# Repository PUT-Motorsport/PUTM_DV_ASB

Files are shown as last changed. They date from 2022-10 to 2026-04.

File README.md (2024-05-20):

# PUTM_DV_ASB_2023
Autonomus Brake System PCB and Software for PM07

Functionality:
Solenoid valves control,
Pressure sensors data acquisition,
Functional safety, and hard-wired logic implementation,
Autonomous System SDC driver,
RES communication bridge.

Important links:

FSG Rules:
fsg.one/rules

Previous board (unusable)

ASF Examples:
https://www.formulastudent.de/academy/hands-on/asf/

FSG Academy:
https://www.formulastudent.de/fileadmin/user_upload/all/2022/important_docs/FSG21_AS_Beginners_Guide_v1.0.pdf

Jakub's Mechanical construction:
https://files.podio.com/1561594165

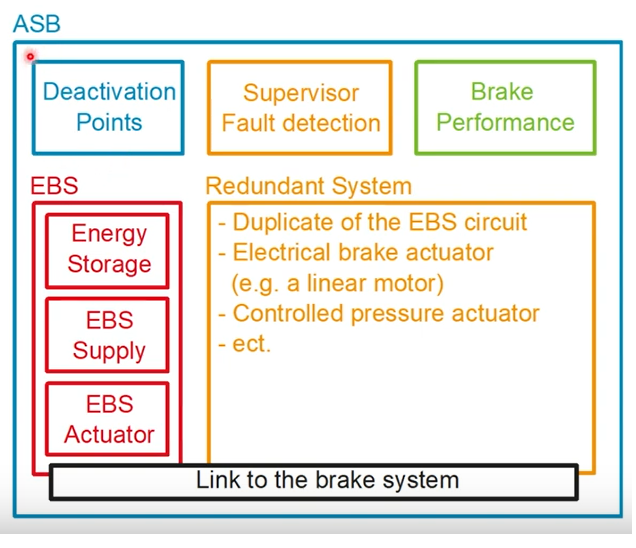
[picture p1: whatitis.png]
ASB


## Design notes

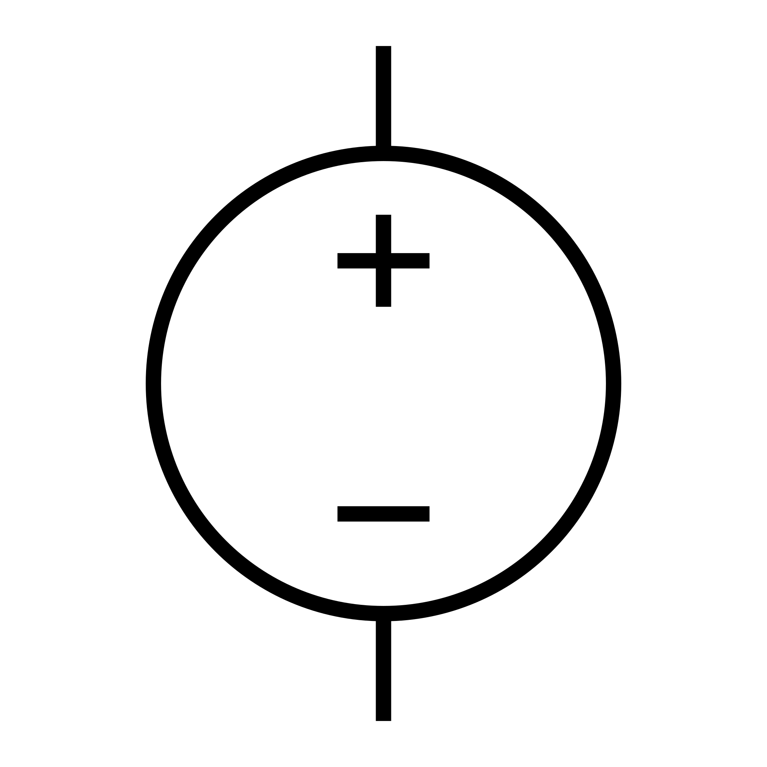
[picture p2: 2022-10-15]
hardware/Voltage_Source.svg.png

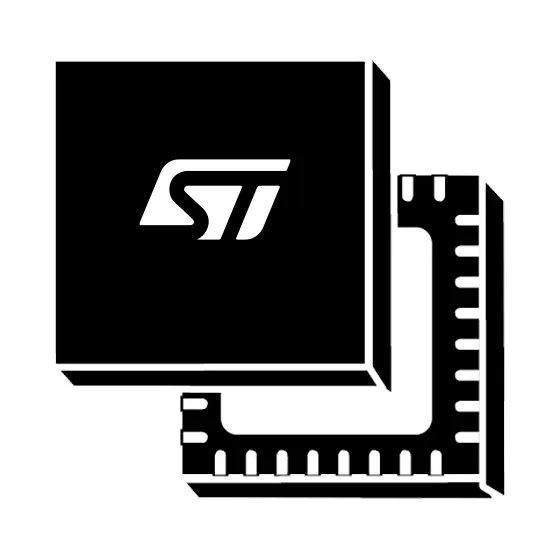
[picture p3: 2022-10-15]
hardware/ufqfpn-48-7x7x0_6.webp

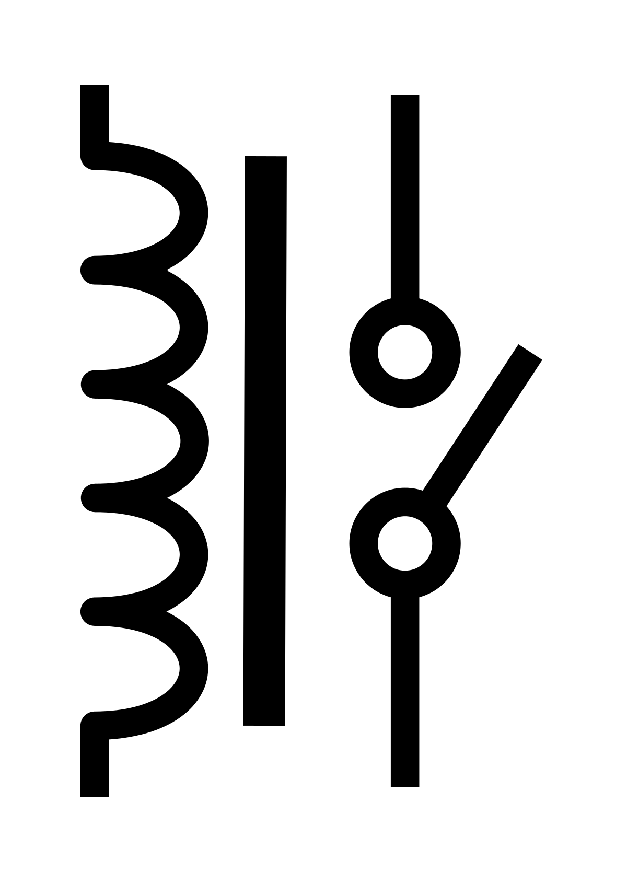
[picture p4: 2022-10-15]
hardware/1200px-SPST-NO_relay_symbol.svg.png

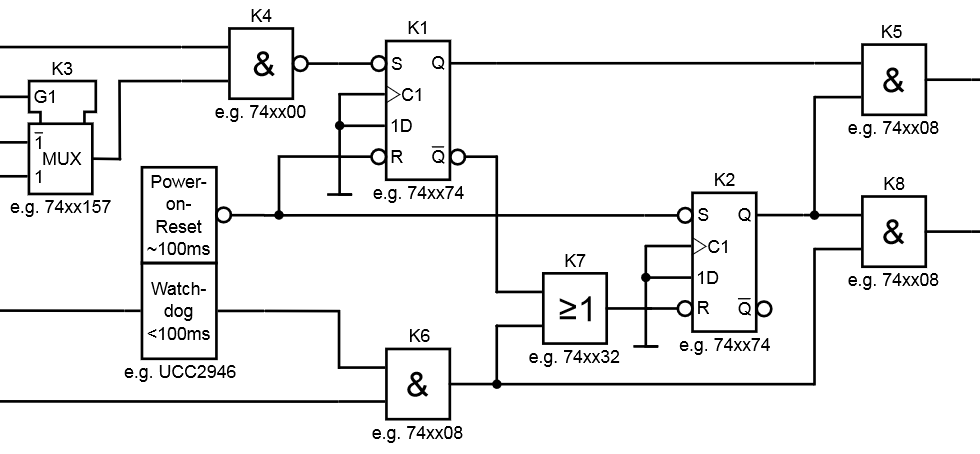
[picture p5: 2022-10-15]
hardware/reference.bmp

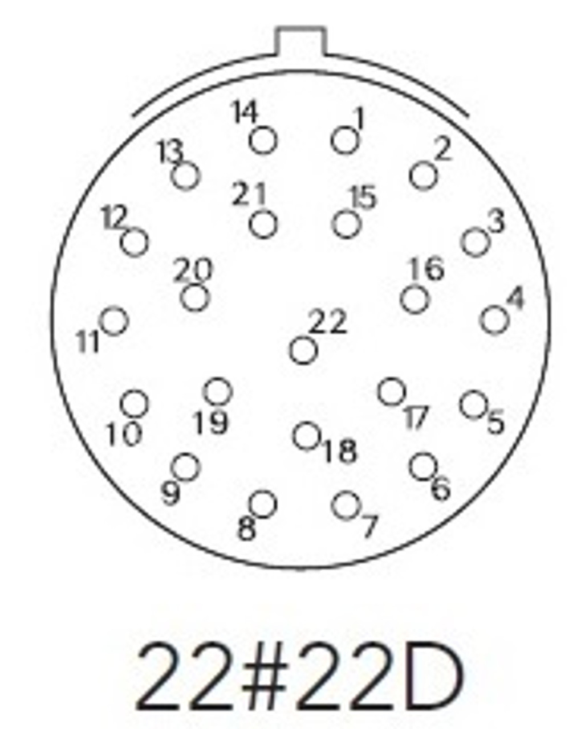
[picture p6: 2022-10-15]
hardware/1235k__19089.jpg

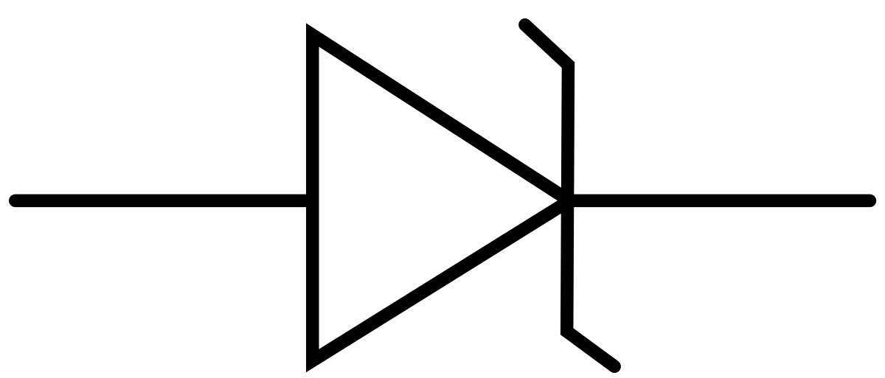
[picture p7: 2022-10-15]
hardware/1200px-Zener_diode_symbol-2.svg.png

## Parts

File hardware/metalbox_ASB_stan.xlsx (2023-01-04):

Designator | Footprint | Quantity | Value | LCSC Part #
C1 | C_0603_1608Metric_Pad1.08x0.95mm_HandSolder | 1 | 10n 1%
C10, C12, C14, C18, C2, C23, C27, C28, C32, C33, C4, C7, C8, C9 | C_0603_1608Metric_Pad1.08x0.95mm_HandSolder | 14 | 100nF
C11, C13 | C_0603_1608Metric_Pad1.08x0.95mm_HandSolder | 2 | 22pF
C15 | C_0805_2012Metric_Pad1.18x1.45mm_HandSolder | 1 | 100nF
C16, C17, C19 | C_0603_1608Metric_Pad1.08x0.95mm_HandSolder | 3 | 100n
C20 | C_0603_1608Metric_Pad1.08x0.95mm_HandSolder | 1 | 10u
C29, C30, C31, C5 | C_0603_1608Metric_Pad1.08x0.95mm_HandSolder | 4 | 10nF
C3 | C_0603_1608Metric_Pad1.08x0.95mm_HandSolder | 1 | 4,7nF 1%
C34, C35, C36 | C_0603_1608Metric_Pad1.08x0.95mm_HandSolder | 3 | 5.6n
C37, C38, C39 | C_0603_1608Metric | 3 | 100nF
C6 | C_0603_1608Metric_Pad1.08x0.95mm_HandSolder | 1 | 1uF
Cb_infltr1 | CP_Elec_4x5.4 | 1 | 4,7uF 3Ohm
Cboot1 | C_0402_1005Metric_Pad0.74x0.62mm_HandSolder | 1 | 100nF 1mOhm
Cf_infltr1, Cf_infltr2, Cf_infltr3 | C_1210_3225Metric_Pad1.33x2.70mm_HandSolder | 3 | 10uF 1mOhm
Cin1 | C_0805_2012Metric_Pad1.18x1.45mm_HandSolder | 1 | 4,7uF 1mOhm
Cinx1 | C_0805_2012Metric_Pad1.18x1.45mm_HandSolder | 1 | 100nF 64mOhm
Cout1 | C_1206_3216Metric_Pad1.33x1.80mm_HandSolder | 1 | 47uF 3,037mOhm
D1, D10, D13, D14, D15 | D_SOD-323_HandSoldering | 5 | BZX38450-C3V3-QX
D11 | LED_0603_1608Metric_Pad1.05x0.95mm_HandSolder | 1 | LED 5V
D12, D3, D4, D5 | D_SMA_Handsoldering | 4 | SK36A
D16, D17, D18, D6 | LED_0603_1608Metric_Pad1.05x0.95mm_HandSolder | 4 | LED
D2 | SOT-23 | 1 | PESD2CAN.215
D7 | D_SMB | 1 | SD24-SOD323
D8 | LED_0603_1608Metric_Pad1.05x0.95mm_HandSolder | 1 | LED 3.3
F1 | Fuse_1206_3216Metric | 1 | 1A
IC1 | SOIC127P600X175-8N | 1 | UCC2946DG4
IC2, IC3 | SOP65P400X130-8N | 2 | SN74LVC1G74DCTR
J1 | M80-5L104YYMC | 1 | SAFETY_SUPPLY
J2 | PinHeader_1x05_P2.54mm_Vertical | 1 | SWDIO_CONN
J3 | M80-5L104YYMC | 1 | SENSORS
J4 | M80-5L104YYMC | 1 | VALVES
J5 | M80-5L112YYMC | 1 | MAIN
JP1 | PinHeader_1x02_P2.54mm_Vertical | 1 | Jumper_NC_Small
K1, K2 | Relay_DPDT_Finder_30.22 | 2 | FINDER-30.22
L1 | L_0805_2012Metric | 1 | 10u
LF_infltr1 | L_0805_2012Metric_Pad1.05x1.20mm_HandSolder | 1 | 1.5uH 260mOhm
L_SW1 | L_Bourns_EBS | 1 | 22uH 36mOhm
PUTM_LOGO | PUTM_LOGO_15mm | 1 | LOGO
Q1, Q2, Q3, Q4 | SOT-23 | 4 | BSS123
R1, R14, R16, R18, R19, R40, R43, R46 | R_0603_1608Metric_Pad0.98x0.95mm_HandSolder | 8 | 1k
R10, R28, R30, R32 | R_0603_1608Metric_Pad0.98x0.95mm_HandSolder | 4 | 22k
R11, R29, R31, R33 | R_0603_1608Metric_Pad0.98x0.95mm_HandSolder | 4 | 3k
R12, R15, R17, R27, R3, R6, R7 | R_0603_1608Metric_Pad0.98x0.95mm_HandSolder | 7 | 10k
R13 | R_0603_1608Metric_Pad0.98x0.95mm_HandSolder | 1 | 120R
R2, R20, R25, R35, R36, R37, R4, R47, R5 | R_0603_1608Metric_Pad0.98x0.95mm_HandSolder | 9 | 2.2k
R38, R41, R44 | R_0603_1608Metric_Pad0.98x0.95mm_HandSolder | 3 | 3.3k 1%
R39, R42, R45 | R_0603_1608Metric_Pad0.98x0.95mm_HandSolder | 3 | 6.8k 1%
R8 | R_0603_1608Metric_Pad0.98x0.95mm_HandSolder | 1 | 4k7 1%
R9 | R_0603_1608Metric_Pad0.98x0.95mm_HandSolder | 1 | 3k3 1%
Rd_infltr1 | R_0603_1608Metric_Pad0.98x0.95mm_HandSolder | 1 | 0.1R
Rfbb1 | R_0402_1005Metric_Pad0.72x0.64mm_HandSolder | 1 | 10kOhm
Rfbt1 | R_0402_1005Metric_Pad0.72x0.64mm_HandSolder | 1 | 23,2kOhm
Rpgood1 | R_0603_1608Metric_Pad0.98x0.95mm_HandSolder | 1 | 100kOhm
Rt1 | R_0603_1608Metric_Pad0.98x0.95mm_HandSolder | 1 | 64,9kOhm
TP1 | PinHeader_1x07_P2.54mm_Vertical | 1 | PinHeader_1x07_P2.54mm_Vertical
TP2 | PinHeader_1x06_P2.54mm_Vertical | 1 | PinHeader_1x06_P2.54mm_Vertical
U1 | VSSOP-8_2.3x2mm_P0.5mm | 1 | 74157
U10, U8, U9 | SOT-23-5_HandSoldering | 3 | TSX7191
U11 | TI_SO-PowerPAD-8_ThermalVias | 1 | LMR38010SDDAR
U2 | TSSOP-14_4.4x5mm_P0.65mm | 1 | 4011
U3 | TSSOP-14_4.4x5mm_P0.65mm | 1 | 4081
U4 | TSSOP-14_4.4x5mm_P0.65mm | 1 | 4071
U5 | LQFP-64_10x10mm_P0.5mm | 1 | STM32L4P5RET6
U6 | SOIC-8_3.9x4.9mm_P1.27mm | 1 | MCP2562-H-SN
U7 | TO-252-3_TabPin2 | 1 | LM1117-3.3
Y1 | Crystal_SMD_3225-4Pin_3.2x2.5mm | 1 | Crystal_GND24

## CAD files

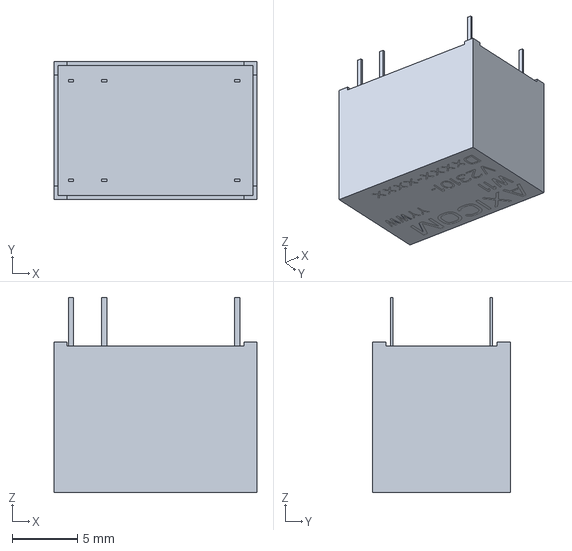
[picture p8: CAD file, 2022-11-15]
hardware/2-1393779-0.stp
15.5 x 10.5 x 14.9 mm

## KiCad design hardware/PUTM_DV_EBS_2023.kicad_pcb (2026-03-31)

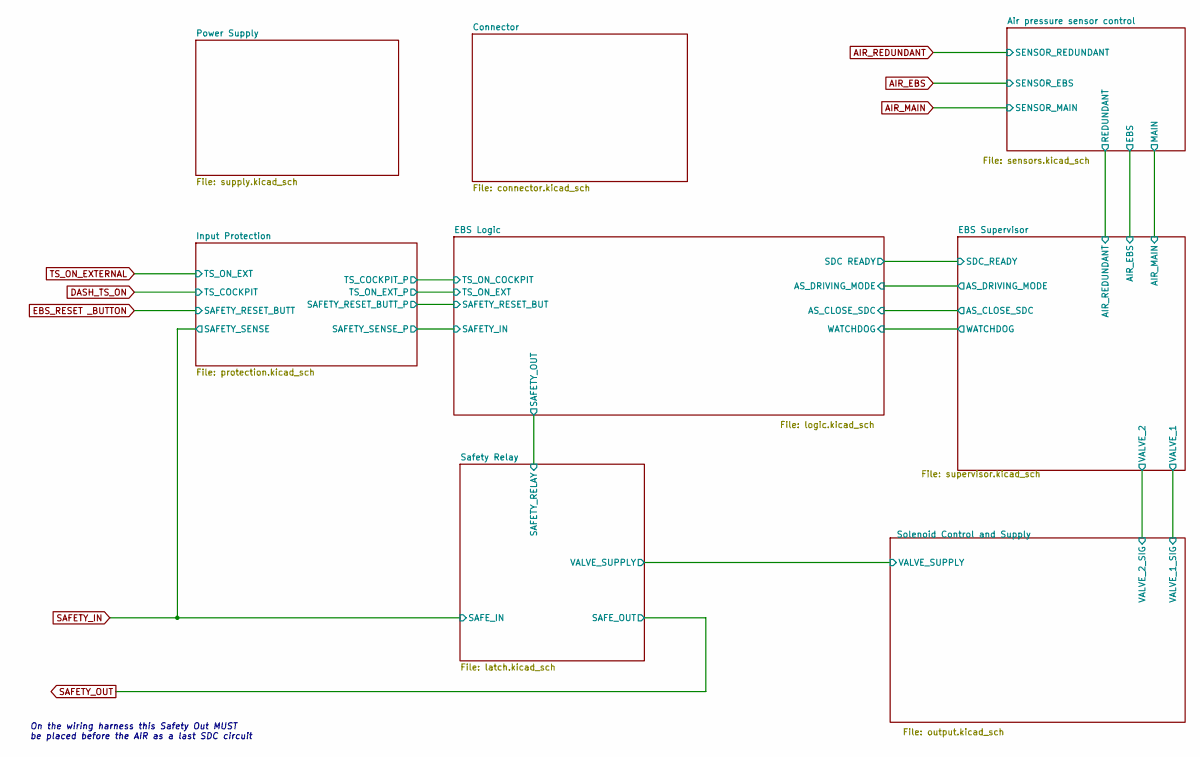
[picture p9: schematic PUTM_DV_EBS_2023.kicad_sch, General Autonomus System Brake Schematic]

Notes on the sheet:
On the wiring harness this Safety Out MUST be placed before the AIR as a last SDC circuit

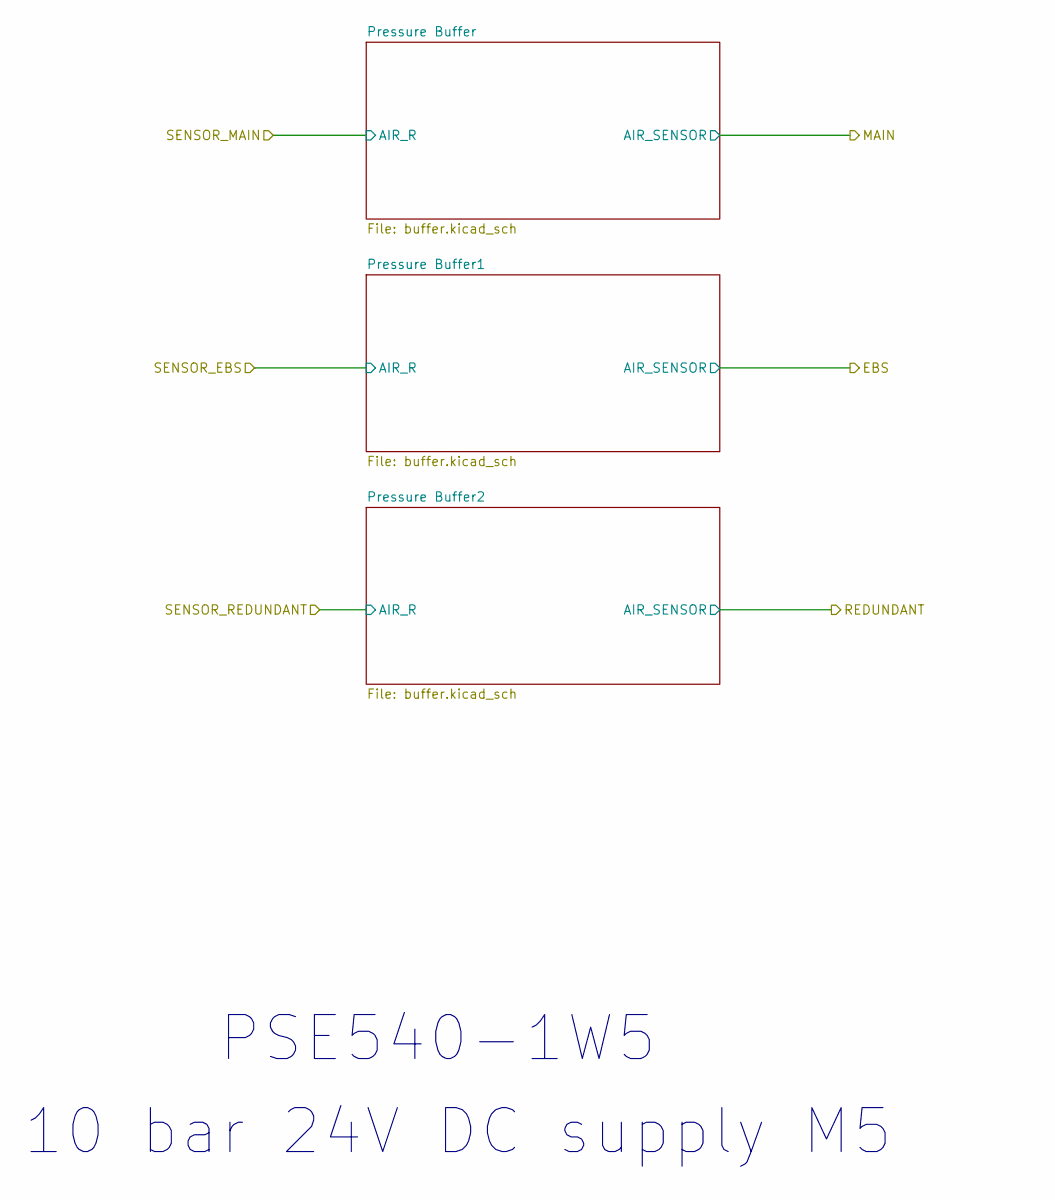
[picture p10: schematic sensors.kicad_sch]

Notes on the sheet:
10 bar 24V DC supply M5
PSE540-1W5

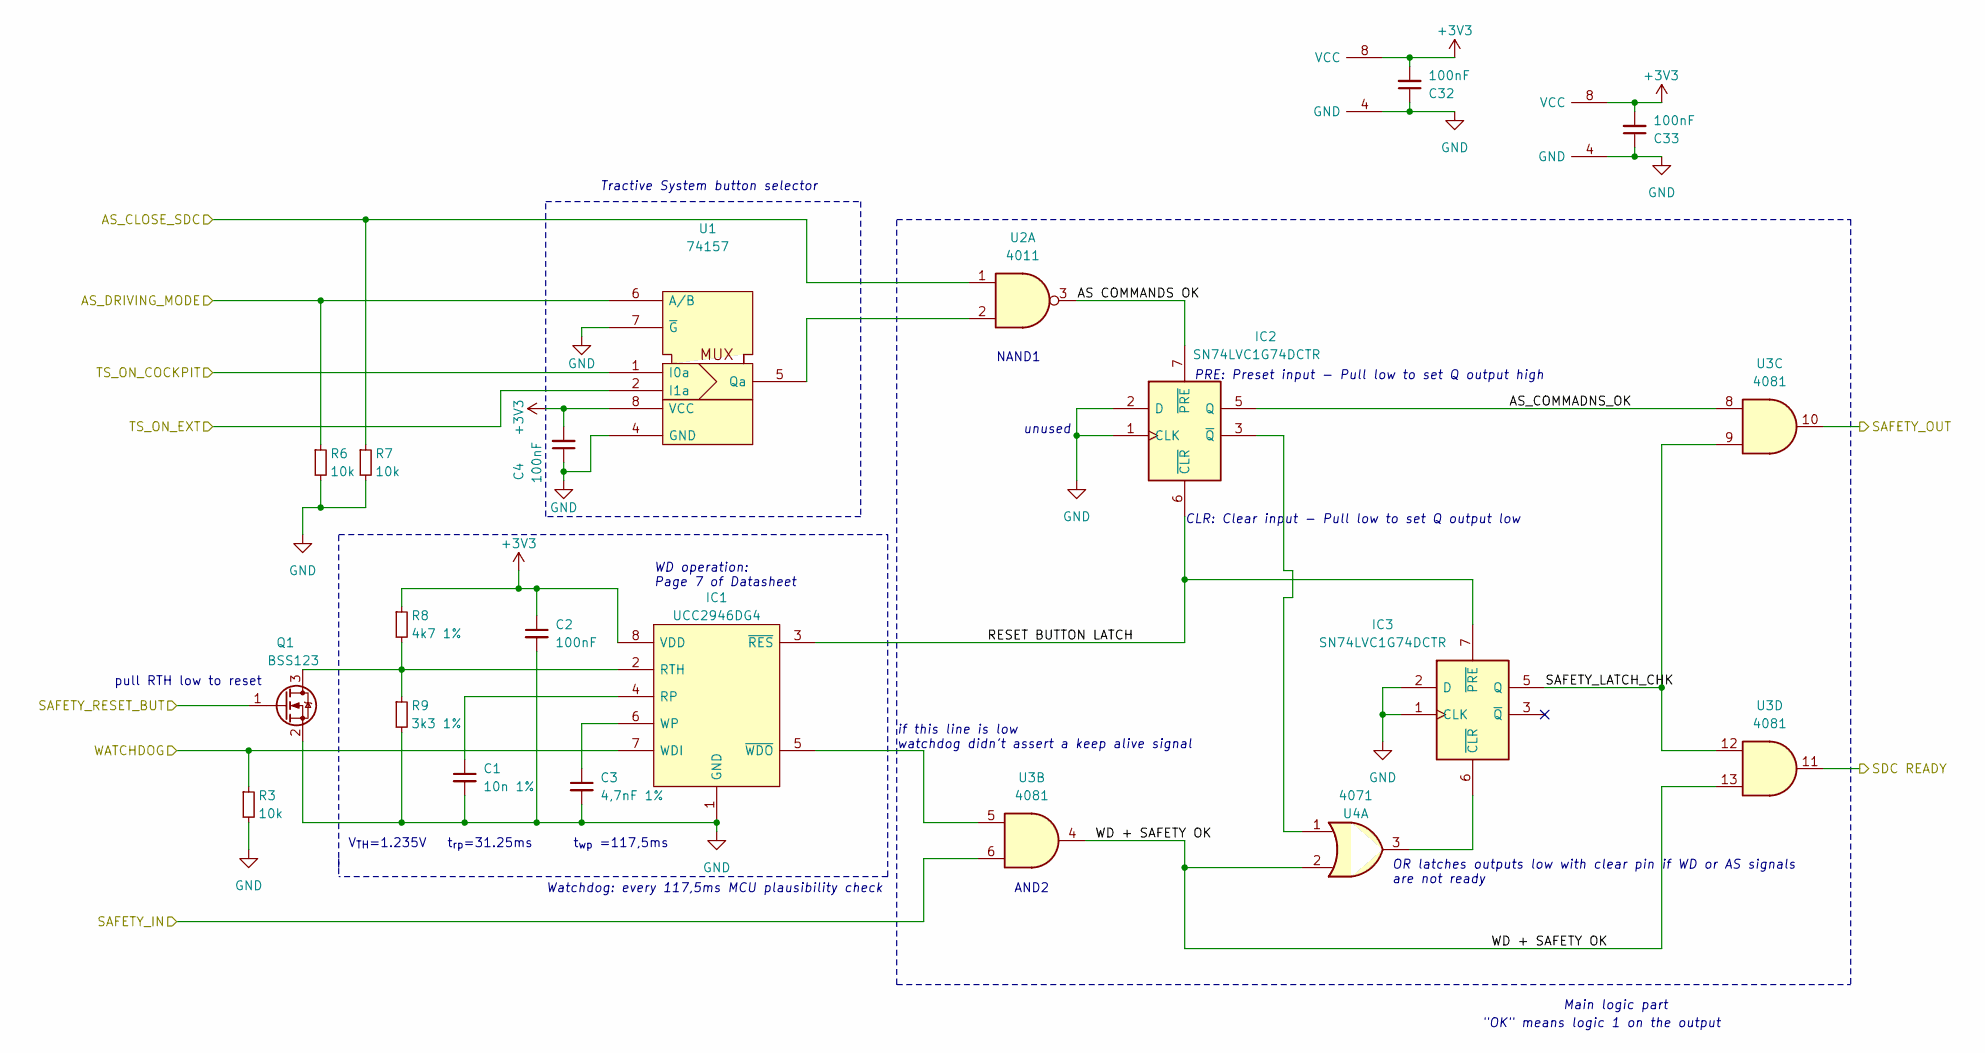
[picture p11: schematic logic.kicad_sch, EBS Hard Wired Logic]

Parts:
C1: 10n 1%; C_0603_1608Metric_Pad1.08x0.95mm_HandSolder
C2, C4, C32, C33: 100nF; C_0603_1608Metric_Pad1.08x0.95mm_HandSolder
C3: 4,7nF 1%; C_0603_1608Metric_Pad1.08x0.95mm_HandSolder
IC1: UCC2946DG4; SOIC127P600X175-8N; Mouser Part Number 595-UCC2946DG4
IC2, IC3: SN74LVC1G74DCTR; SOP65P400X130-8N; Mouser Part Number 595-SN74LVC1G74DCTR
Q1: BSS123; SOT-23
R3, R6, R7: 10k; R_0603_1608Metric_Pad0.98x0.95mm_HandSolder
R8: 4k7 1%; R_0603_1608Metric_Pad0.98x0.95mm_HandSolder
R9: 3k3 1%; R_0603_1608Metric_Pad0.98x0.95mm_HandSolder
U1: 74157; VSSOP-8_2.3x2mm_P0.5mm
U2: 4011; TSSOP-14_4.4x5mm_P0.65mm
U3: 4081; TSSOP-14_4.4x5mm_P0.65mm
U4: 4071; TSSOP-14_4.4x5mm_P0.65mm

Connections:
+3V3: C2.1, C4.2, C32.2, C33.2, IC1.8 (VDD), IC2.8 (VCC), IC3.8 (VCC), R8.1, U1.8 (VCC); also elsewhere on the board
/EBS Logic/AS COMMANDS OK: IC2.7 (~PRE), U2.3; also elsewhere on the board
/EBS Logic/AS_CLOSE_SDC: R7.1, U2.1; also elsewhere on the board
/EBS Logic/AS_COMMADNS_OK: IC2.5 (Q), U3.8
/EBS Logic/AS_DRIVING_MODE: R6.1, U1.6 (A/B); also elsewhere on the board
/EBS Logic/RESET BUTTON LATCH: IC1.3 (~RES), IC2.6 (~CLR), IC3.7 (~PRE); also elsewhere on the board
/EBS Logic/SAFETY_IN: U3.6; also elsewhere on the board
/EBS Logic/SAFETY_LATCH_CHK: IC3.5 (Q), U3.9, U3.12; also elsewhere on the board
/EBS Logic/SAFETY_OUT: U3.10; also elsewhere on the board
/EBS Logic/SAFETY_RESET_BUT: Q1.1 (G); also elsewhere on the board
/EBS Logic/SDC READY: U3.11; also elsewhere on the board
/EBS Logic/TS_ON_COCKPIT: U1.1 (I0a); also elsewhere on the board
/EBS Logic/TS_ON_EXT: U1.2 (I1a); also elsewhere on the board
/EBS Logic/WATCHDOG: IC1.7 (WDI), R3.1; also elsewhere on the board
/EBS Logic/WD + SAFETY OK: U3.4, U3.13, U4.2; also elsewhere on the board
GND: C1.2, C2.2, C3.2, C4.1, C32.1, C33.1, IC1.1 (GND), IC2.1 (CLK), IC2.2 (D), IC2.4 (GND), IC3.1 (CLK), IC3.2 (D), IC3.4 (GND), Q1.2 (S), R3.2, R6.2, R7.2, R9.2, U1.4 (GND), U1.7 (~G); also elsewhere on the board
unnamed: C1.1, IC1.4 (RP)
unnamed: C3.1, IC1.6 (WP)
unnamed 65: IC1.2 (RTH), Q1.3 (D), R8.2, R9.1; also elsewhere on the board
unnamed 66: IC1.5 (~WDO), U3.5; also elsewhere on the board
unnamed: IC2.3 (~Q), U4.1
unnamed: IC3.6 (~CLR), U4.3
unnamed: U1.5 (Qa), U2.2

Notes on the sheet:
OR latches outputs low with clear pin if WD or AS signals are not ready
unused
V_{TH}=1.235V
"OK" means logic 1 on the output
Watchdog: every 117,5ms MCU plausibility check
Tractive System button selector
pull RTH low to reset
PRE: Preset input − Pull low to set Q output high
Main logic part
CLR: Clear input − Pull low to set Q output low
AND2
NAND1
WD operation: Page 7 of Datasheet
if this line is low watchdog didn't assert a keep alive signal
t_{wp} =117,5ms
t_{rp}=31.25ms

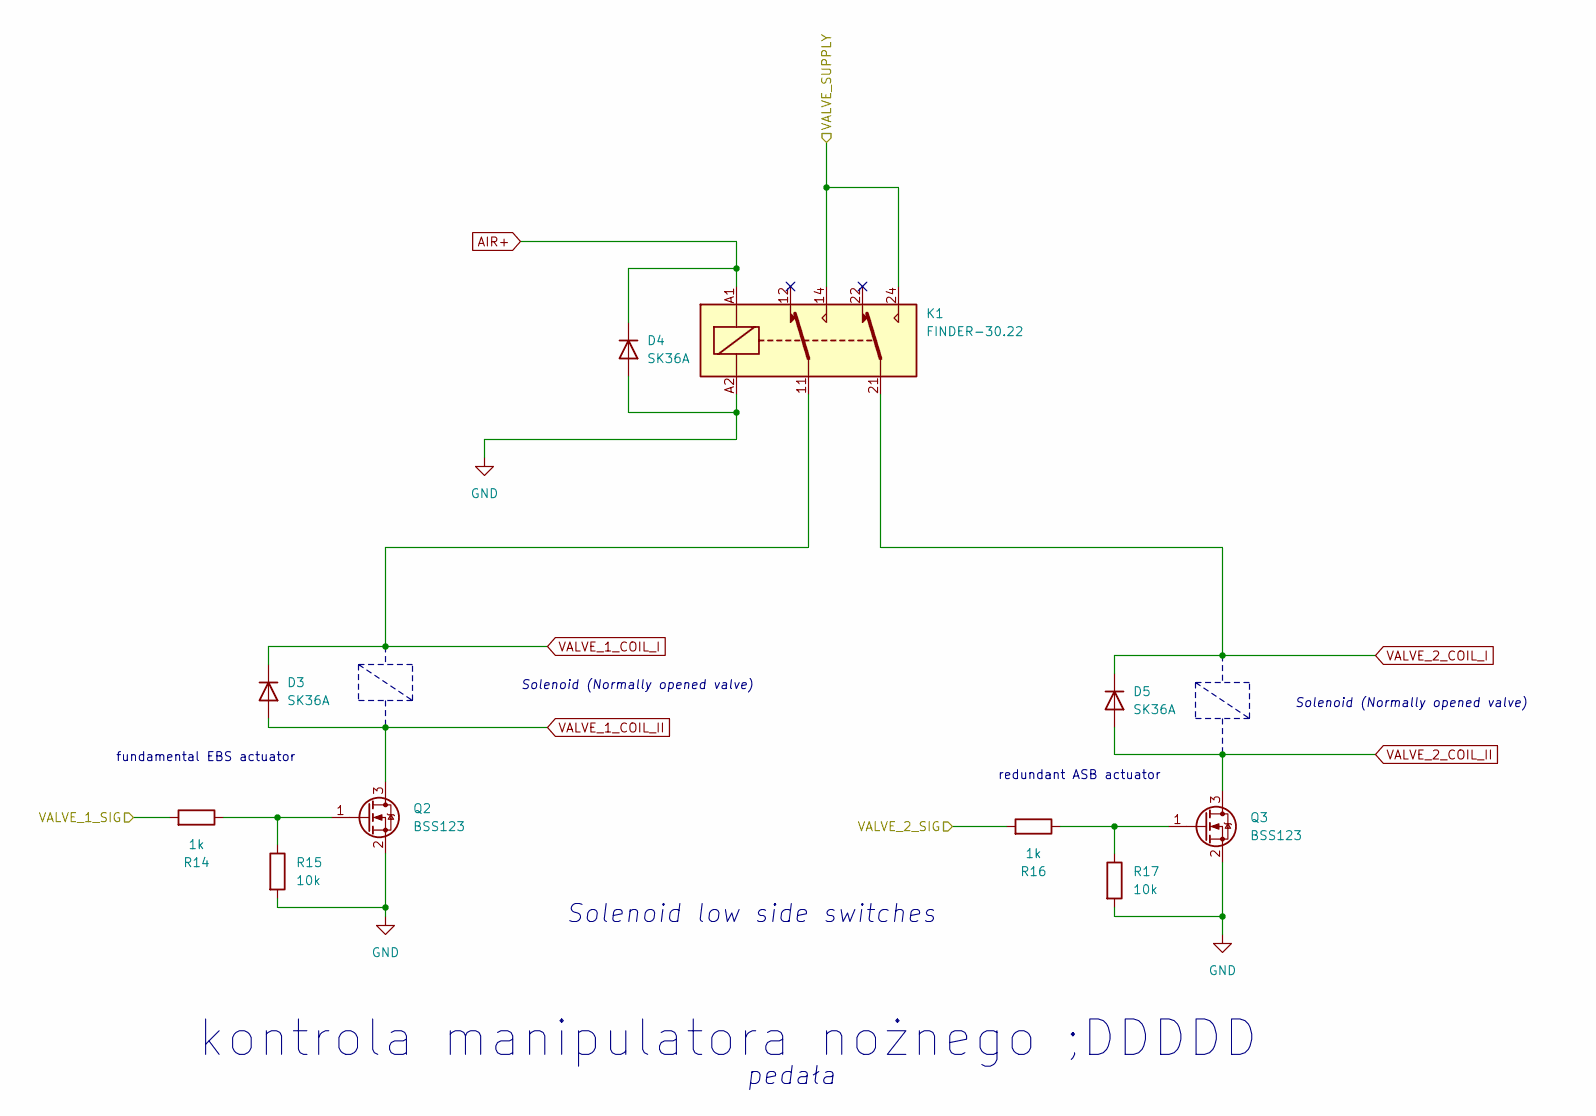
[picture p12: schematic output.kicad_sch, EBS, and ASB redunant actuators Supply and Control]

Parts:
D3, D4, D5: SK36A; D_SMA_Handsoldering
K1: FINDER-30.22; Relay_DPDT_Finder_30.22
Q2, Q3: BSS123; SOT-23
R14, R16: 1k; R_0603_1608Metric_Pad0.98x0.95mm_HandSolder
R15, R17: 10k; R_0603_1608Metric_Pad0.98x0.95mm_HandSolder

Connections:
/EBS Supervisor/VALVE_1: R14.2; also elsewhere on the board
/EBS Supervisor/VALVE_2: R16.2; also elsewhere on the board
/Safety Relay/VALVE_SUPPLY: K1.14, K1.24; also elsewhere on the board
AIR+: D4.1 (K), K1.A1; also elsewhere on the board
GND: D4.2 (A), K1.A2, Q2.2 (S), Q3.2 (S), R15.2, R17.2; also elsewhere on the board
unnamed: Q2.1 (G), R14.1, R15.1
unnamed: Q3.1 (G), R16.1, R17.1
VALVE_1_COIL_I: D3.1 (K), K1.11; also elsewhere on the board
VALVE_1_COIL_II: D3.2 (A), Q2.3 (D); also elsewhere on the board
VALVE_2_COIL_I: D5.1 (K), K1.21; also elsewhere on the board
VALVE_2_COIL_II: D5.2 (A), Q3.3 (D); also elsewhere on the board

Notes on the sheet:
Solenoid (Normally opened valve)
Solenoid low side switches
fundamental EBS actuator
pedała
redundant ASB actuator
kontrola manipulatora nożnego ;DDDDD

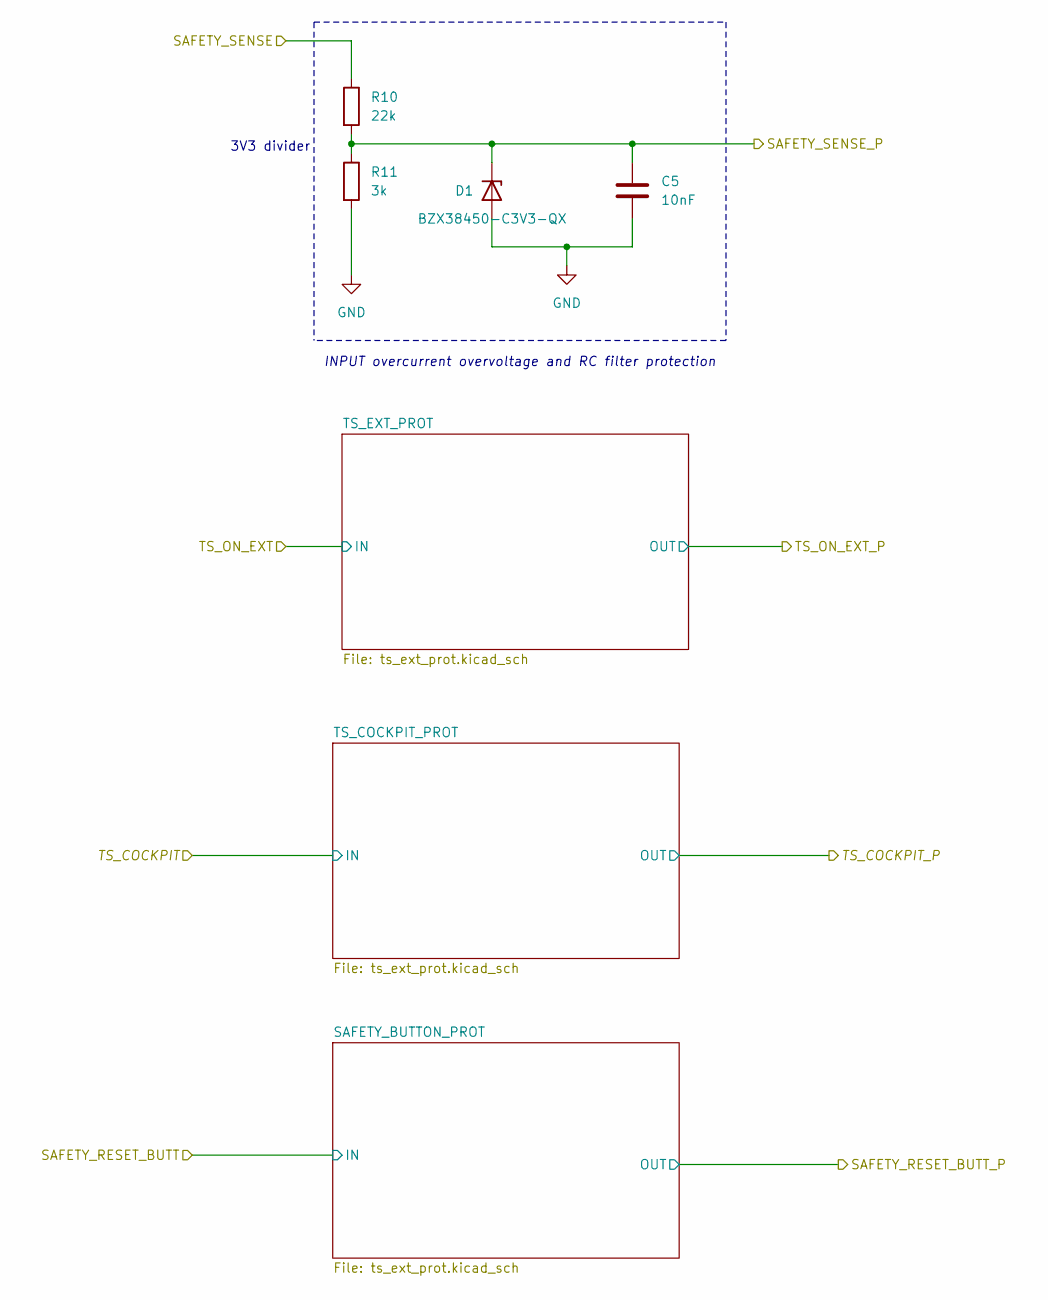
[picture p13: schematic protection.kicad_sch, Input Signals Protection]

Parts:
C5: 10nF; C_0603_1608Metric_Pad1.08x0.95mm_HandSolder
D1: BZX38450-C3V3-QX; D_SOD-323_HandSoldering
R10: 22k; R_0603_1608Metric_Pad0.98x0.95mm_HandSolder
R11: 3k; R_0603_1608Metric_Pad0.98x0.95mm_HandSolder

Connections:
/EBS Logic/SAFETY_IN: C5.1, D1.1 (K), R10.2, R11.1; also elsewhere on the board
GND: C5.2, D1.2 (A), R11.2; also elsewhere on the board
SAFETY_IN: R10.1; also elsewhere on the board

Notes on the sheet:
3V3 divider
INPUT overcurrent overvoltage and RC filter protection

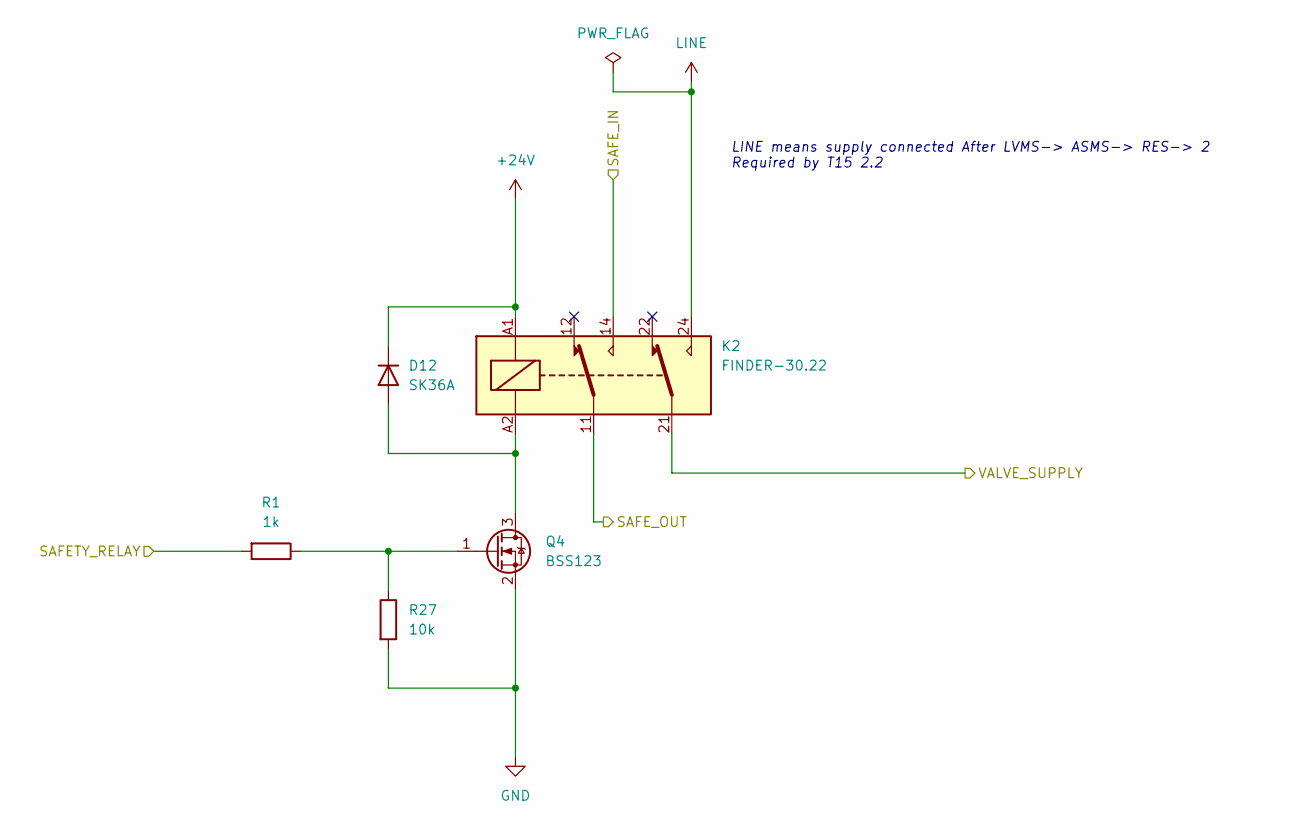
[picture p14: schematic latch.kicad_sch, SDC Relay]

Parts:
D12: SK36A; D_SMA_Handsoldering
K2: FINDER-30.22; Relay_DPDT_Finder_30.22
Q4: BSS123; SOT-23
R1: 1k; R_0603_1608Metric_Pad0.98x0.95mm_HandSolder
R27: 10k; R_0603_1608Metric_Pad0.98x0.95mm_HandSolder

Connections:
+24V: D12.1 (K), K2.A1; also elsewhere on the board
/EBS Logic/SAFETY_OUT: R1.2; also elsewhere on the board
/Safety Relay/VALVE_SUPPLY: K2.21; also elsewhere on the board
GND: Q4.2 (S), R27.2; also elsewhere on the board
LINE: K2.24; also elsewhere on the board
unnamed: D12.2 (A), K2.A2, Q4.3 (D)
unnamed: Q4.1 (G), R1.1, R27.1
SAFETY_IN: K2.14; also elsewhere on the board
SAFETY_OUT: K2.11; also elsewhere on the board

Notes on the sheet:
LINE means supply connected After LVMS-> ASMS-> RES-> 2 Required by T15 2.2

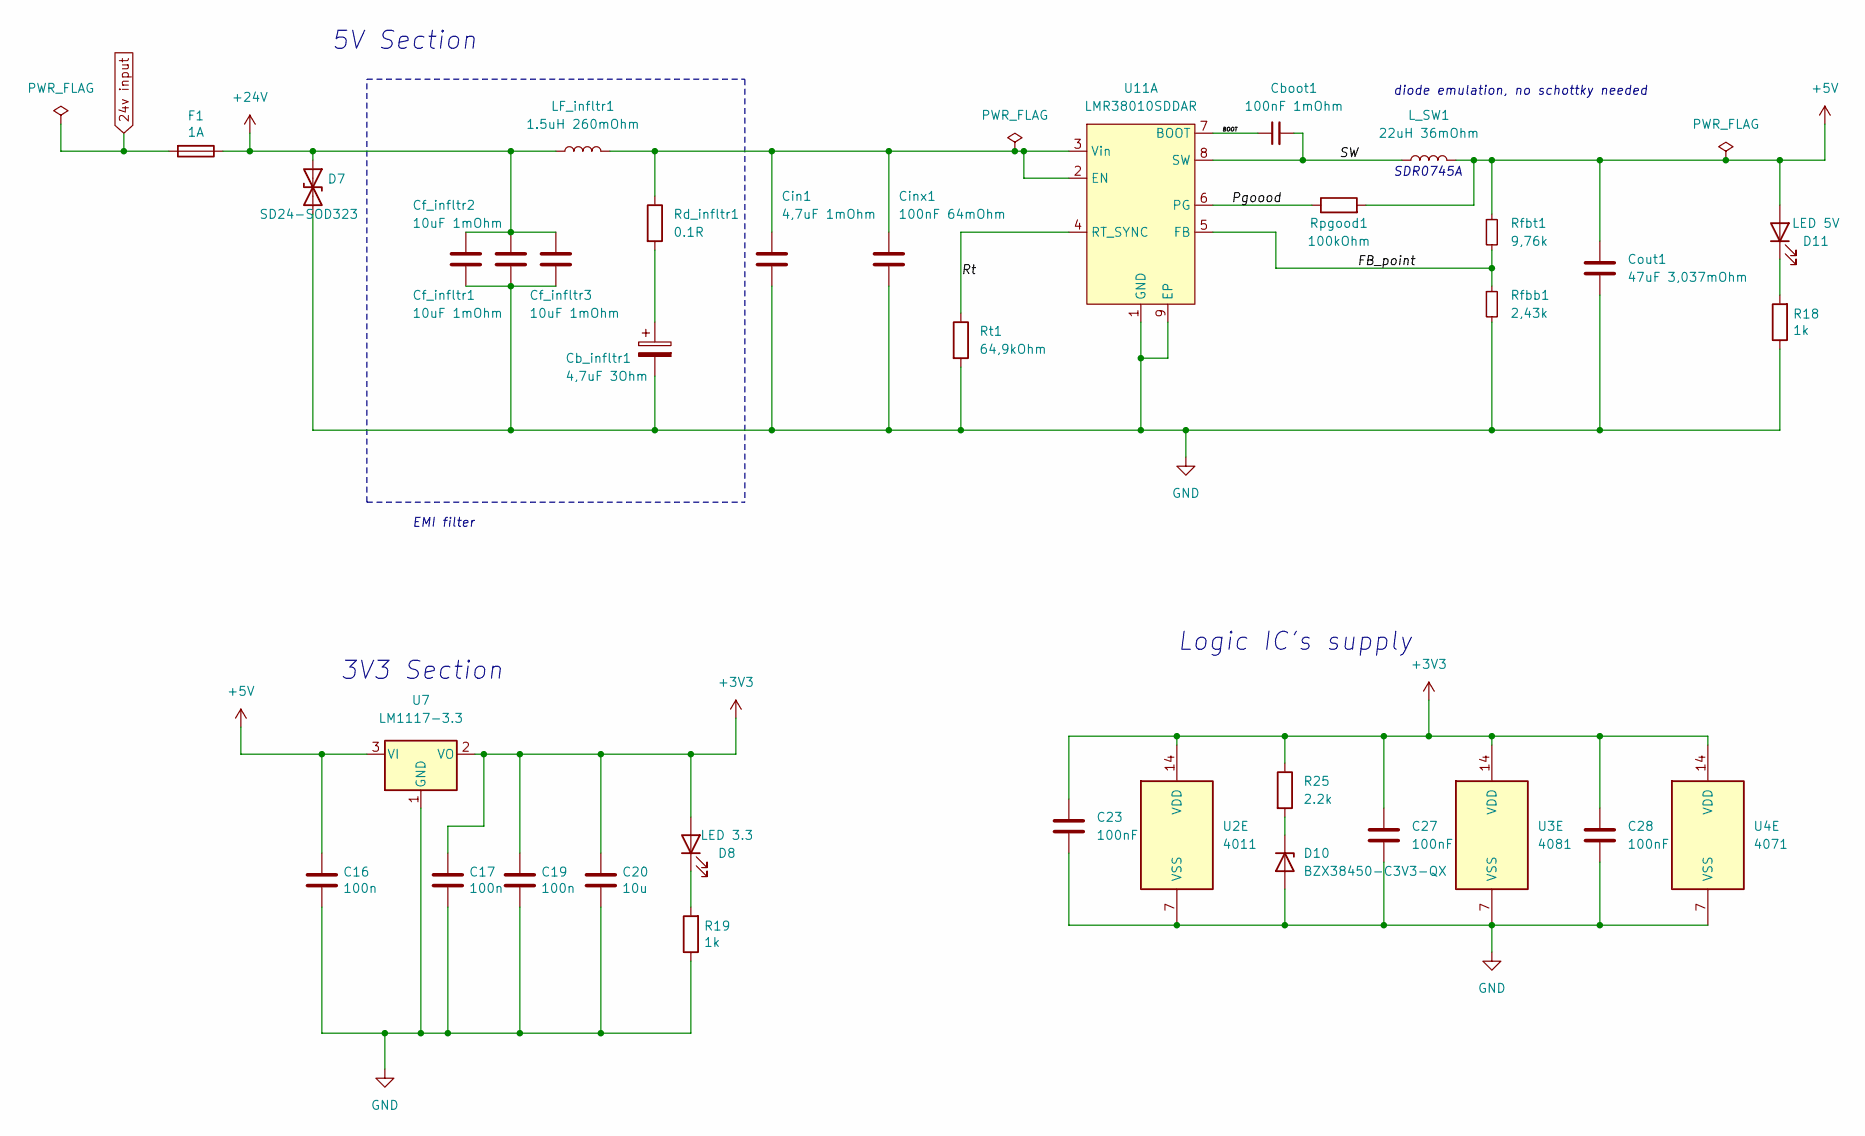
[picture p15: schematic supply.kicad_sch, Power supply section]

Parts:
C16, C17, C19: 100n; C_0603_1608Metric_Pad1.08x0.95mm_HandSolder
C20: 10u; C_0603_1608Metric_Pad1.08x0.95mm_HandSolder
C23: 100nF; C_0201_0603Metric_Pad0.64x0.40mm_HandSolder
C27, C28: 100nF; C_0603_1608Metric_Pad1.08x0.95mm_HandSolder
Cb_infltr1: 4,7uF 3Ohm; CP_Elec_4x5.4
Cboot1: 100nF 1mOhm; C_0402_1005Metric_Pad0.74x0.62mm_HandSolder
Cf_infltr1, Cf_infltr2, Cf_infltr3: 10uF 1mOhm; C_1210_3225Metric_Pad1.33x2.70mm_HandSolder
Cin1: 4,7uF 1mOhm; C_0805_2012Metric_Pad1.18x1.45mm_HandSolder
Cinx1: 100nF 64mOhm; C_0805_2012Metric_Pad1.18x1.45mm_HandSolder
Cout1: 47uF 3,037mOhm; C_1206_3216Metric_Pad1.33x1.80mm_HandSolder
D7: SD24-SOD323; D_SMB
D8: LED 3.3; LED_0603_1608Metric_Pad1.05x0.95mm_HandSolder
D10: BZX38450-C3V3-QX; D_SOD-323_HandSoldering
D11: LED 5V; LED_0603_1608Metric_Pad1.05x0.95mm_HandSolder
F1: 1A; Fuse_1206_3216Metric
LF_infltr1: 1.5uH 260mOhm; L_0805_2012Metric_Pad1.05x1.20mm_HandSolder
L_SW1: 22uH 36mOhm; L_Bourns_EBS
R18, R19: 1k; R_0603_1608Metric_Pad0.98x0.95mm_HandSolder
R25: 2.2k; R_0603_1608Metric_Pad0.98x0.95mm_HandSolder
Rd_infltr1: 0.1R; R_0603_1608Metric_Pad0.98x0.95mm_HandSolder
Rfbb1: 2,43k; R_0402_1005Metric_Pad0.72x0.64mm_HandSolder
Rfbt1: 9,76k; R_0402_1005Metric_Pad0.72x0.64mm_HandSolder
Rpgood1: 100kOhm; R_0603_1608Metric_Pad0.98x0.95mm_HandSolder
Rt1: 64,9kOhm; R_0603_1608Metric_Pad0.98x0.95mm_HandSolder
U2: 4011; TSSOP-14_4.4x5mm_P0.65mm
U3: 4081; TSSOP-14_4.4x5mm_P0.65mm
U4: 4071; TSSOP-14_4.4x5mm_P0.65mm
U7: LM1117-3.3; TO-252-3_TabPin2
U11: LMR38010SDDAR; TI_SO-PowerPAD-8_ThermalVias

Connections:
24v input: F1.2; also elsewhere on the board
+3V3: C17.1, C19.1, C20.1, C23.1, C27.1, C28.1, D8.2 (A), R25.1, U2.14 (VDD), U3.14 (VDD), U4.14 (VDD), U7.2 (VO); also elsewhere on the board
+5V: C16.1, Cout1.1, D11.2 (A), L_SW1.2, Rfbt1.1, Rpgood1.2, U7.3 (VI); also elsewhere on the board
+24V: Cf_infltr1.1, Cf_infltr2.1, Cf_infltr3.1, D7.1 (A1), F1.1, LF_infltr1.1; also elsewhere on the board
/Power Supply/BOOT: Cboot1.1, U11.7 (BOOT)
/Power Supply/FB_point: Rfbb1.1, Rfbt1.2, U11.5 (FB)
/Power Supply/Pgoood: Rpgood1.1, U11.6 (PG)
/Power Supply/Rt: Rt1.1, U11.4 (RT_SYNC)
/Power Supply/SW: Cboot1.2, L_SW1.1, U11.8 (SW)
GND: C16.2, C17.2, C19.2, C20.2, C23.2, C27.2, C28.2, Cb_infltr1.2, Cf_infltr1.2, Cf_infltr2.2, Cf_infltr3.2, Cin1.2, Cinx1.2, Cout1.2, D7.2 (A2), D10.2 (A), R18.1, R19.1, Rfbb1.2, Rt1.2, U2.7 (VSS), U3.7 (VSS), U4.7 (VSS), U7.1 (GND), U11.1 (GND), U11.9 (EP); also elsewhere on the board
unnamed: Cb_infltr1.1, Rd_infltr1.2
unnamed: Cin1.1, Cinx1.1, LF_infltr1.2, Rd_infltr1.1, U11.2 (EN), U11.3 (Vin)
unnamed: D8.1 (K), R19.2
unnamed: D10.1 (K), R25.2
unnamed: D11.1 (K), R18.2

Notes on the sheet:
diode emulation, no schottky needed
3V3 Section
EMI filter
Logic IC's supply
5V Section
SDR0745A

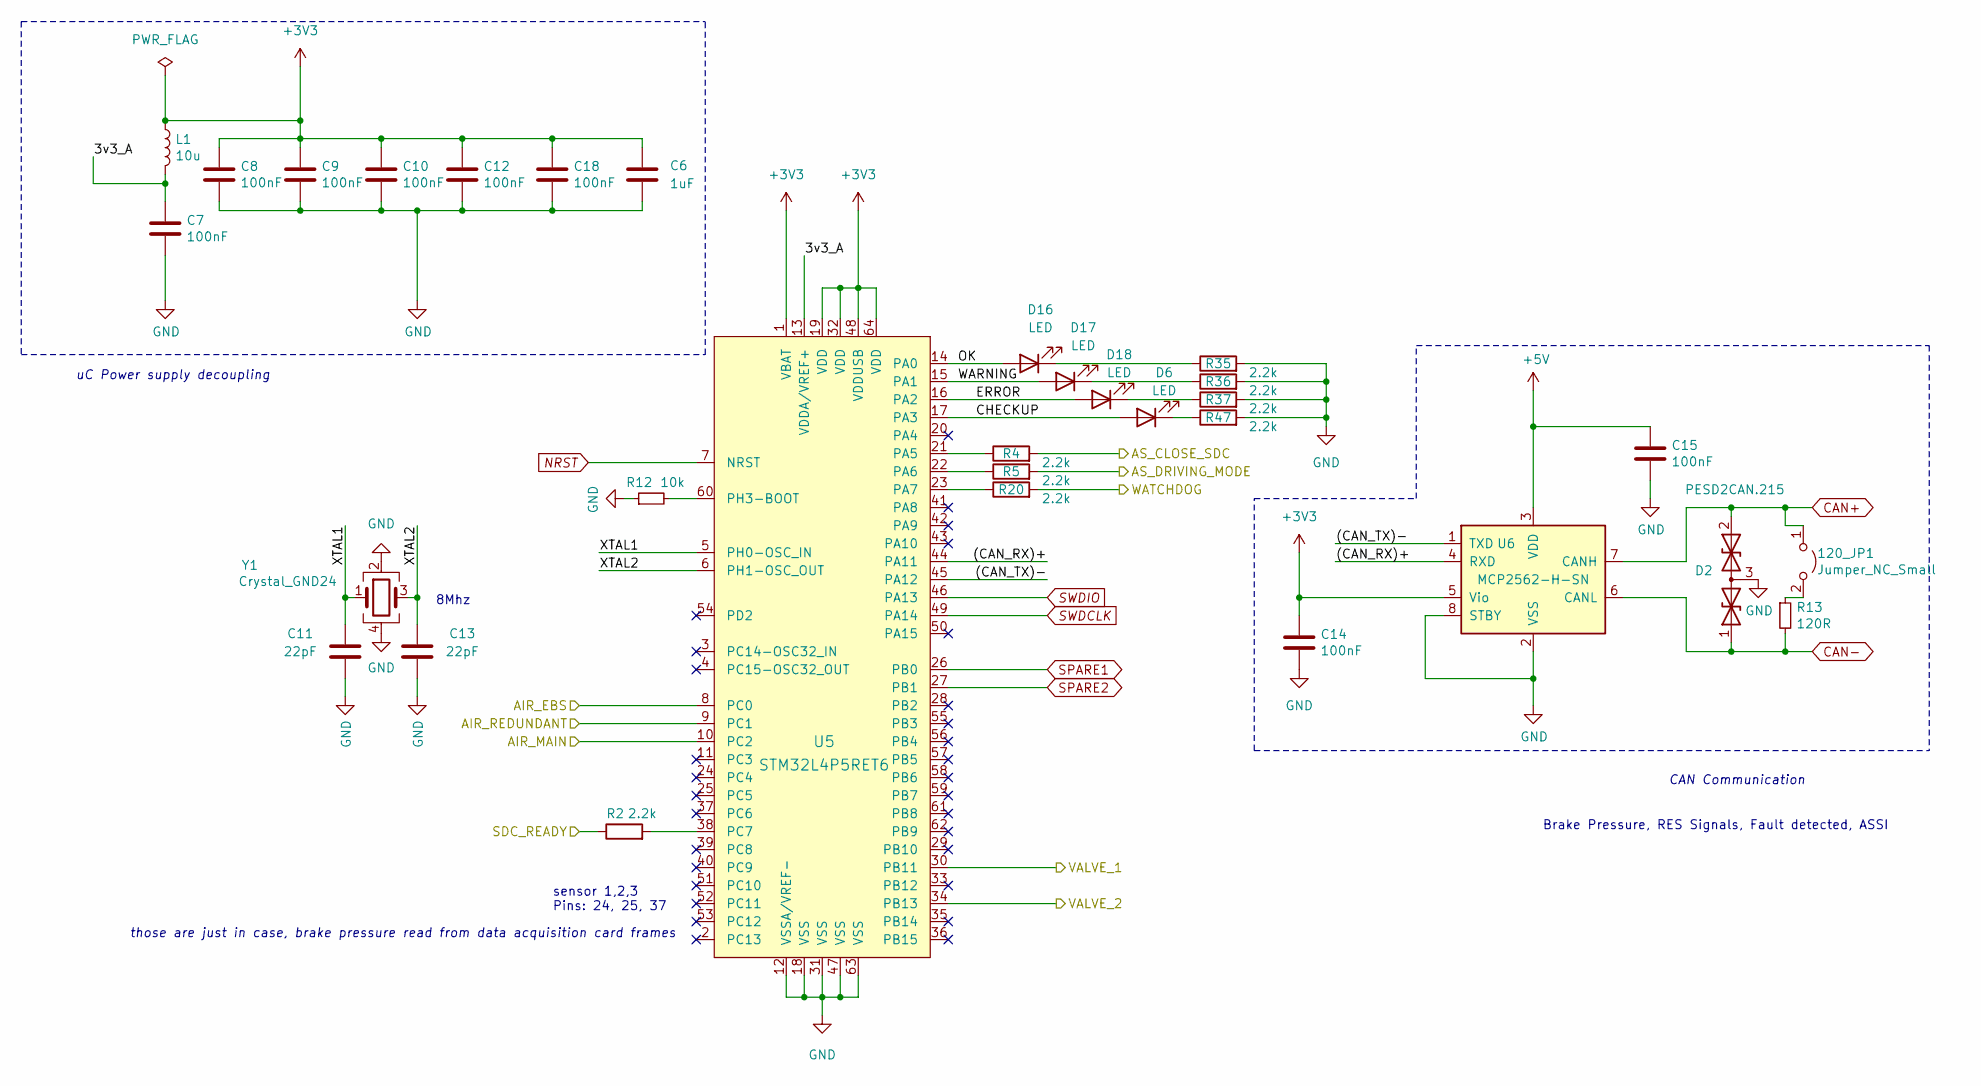
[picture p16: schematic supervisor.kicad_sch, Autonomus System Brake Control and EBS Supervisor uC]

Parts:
120_JP1: Jumper_NC_Small; PinHeader_1x02_P2.54mm_Vertical
C6: 1uF; C_0603_1608Metric_Pad1.08x0.95mm_HandSolder
C7, C8, C9, C10, C12, C14, C18: 100nF; C_0603_1608Metric_Pad1.08x0.95mm_HandSolder
C11, C13: 22pF; C_0603_1608Metric_Pad1.08x0.95mm_HandSolder
C15: 100nF; C_0805_2012Metric_Pad1.18x1.45mm_HandSolder
D2: PESD2CAN.215; SOT-23
D6, D16, D17, D18: LED; LED_0603_1608Metric_Pad1.05x0.95mm_HandSolder
L1: 10u; L_0805_2012Metric
R2, R4, R5, R20, R35, R36, R37, R47: 2.2k; R_0603_1608Metric_Pad0.98x0.95mm_HandSolder
R12: 10k; R_0603_1608Metric_Pad0.98x0.95mm_HandSolder
R13: 120R; R_0603_1608Metric_Pad0.98x0.95mm_HandSolder
U5: STM32L4P5RET6; LQFP-64_10x10mm_P0.5mm
U6: MCP2562-H-SN; SOIC-8_3.9x4.9mm_P1.27mm
Y1: Crystal_GND24; Crystal_SMD_3225-4Pin_3.2x2.5mm

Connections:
+3V3: C6.1, C8.1, C9.1, C10.1, C12.1, C14.1, C18.1, L1.1, U5.1 (VBAT), U5.19 (VDD), U5.32 (VDD), U5.48 (VDDUSB), U5.64 (VDD), U6.5 (Vio); also elsewhere on the board
+5V: C15.1, U6.3 (VDD); also elsewhere on the board
/Air pressure sensor control/EBS: U5.8 (PC0); also elsewhere on the board
/Air pressure sensor control/MAIN: U5.10 (PC2); also elsewhere on the board
/Air pressure sensor control/REDUNDANT: U5.9 (PC1); also elsewhere on the board
/EBS Logic/AS_CLOSE_SDC: R4.2; also elsewhere on the board
/EBS Logic/AS_DRIVING_MODE: R5.2; also elsewhere on the board
/EBS Logic/SDC READY: R2.1; also elsewhere on the board
/EBS Logic/WATCHDOG: R20.2; also elsewhere on the board
/EBS Supervisor/3v3_A: C7.1, L1.2, U5.13 (VDDA/VREF+)
/EBS Supervisor/(CAN_RX)+: U5.44 (PA11), U6.4 (RXD)
/EBS Supervisor/(CAN_TX)-: U5.45 (PA12), U6.1 (TXD)
/EBS Supervisor/CHECKUP: D6.2 (A), U5.17 (PA3)
/EBS Supervisor/ERROR: D18.2 (A), U5.16 (PA2)
/EBS Supervisor/OK: D16.2 (A), U5.14 (PA0)
/EBS Supervisor/VALVE_1: U5.30 (PB11); also elsewhere on the board
/EBS Supervisor/VALVE_2: U5.34 (PB13); also elsewhere on the board
/EBS Supervisor/WARNING: D17.2 (A), U5.15 (PA1)
/EBS Supervisor/XTAL1: C11.1, U5.5 (PH0-OSC_IN), Y1.1
/EBS Supervisor/XTAL2: C13.1, U5.6 (PH1-OSC_OUT), Y1.3
CAN+: 120_JP1.1 (A), D2.2 (A2), U6.7 (CANH); also elsewhere on the board
CAN-: D2.1 (A1), R13.2, U6.6 (CANL); also elsewhere on the board
GND: C6.2, C7.2, C8.2, C9.2, C10.2, C11.2, C12.2, C13.2, C14.2, C15.2, C18.2, D2.3 (common), R12.1, R35.2, R36.2, R37.2, R47.2, U5.12 (VSSA/VREF-), U5.18 (VSS), U5.31 (VSS), U5.47 (VSS), U5.63 (VSS), U6.2 (VSS), U6.8 (STBY), Y1.2, Y1.4; also elsewhere on the board
NRST: U5.7 (NRST); also elsewhere on the board
unnamed: 120_JP1.2 (B), R13.1
unnamed: D6.1 (K), R47.1
unnamed: D16.1 (K), R35.1
unnamed: D17.1 (K), R36.1
unnamed: D18.1 (K), R37.1
unnamed: R2.2, U5.38 (PC7)
unnamed: R4.1, U5.21 (PA5)
unnamed: R5.1, U5.22 (PA6)
unnamed: R12.2, U5.60 (PH3-BOOT)
unnamed: R20.1, U5.23 (PA7)
SWDCLK: U5.49 (PA14); also elsewhere on the board
SWDIO: U5.46 (PA13); also elsewhere on the board

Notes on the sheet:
CAN Communication
those are just in case, brake pressure read from data acquisition card frames
sensor 1,2,3 Pins: 24, 25, 37
8Mhz
uC Power supply decoupling
Brake Pressure, RES Signals, Fault detected, ASSI

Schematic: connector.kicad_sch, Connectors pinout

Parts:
J1: SAFETY_SUPPLY; M80-5L104YYMC
J2: SWDIO_CONN; PinHeader_1x05_P2.54mm_Vertical
J3: SENSORS; M80-5L104YYMC
J4: VALVES; M80-5L104YYMC
J5: MAIN; M80-5L112YYMC

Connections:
24v input: J5.5; also elsewhere on the board
+3V3: J2.1; also elsewhere on the board
AIR+: J5.12; also elsewhere on the board
AIR_EBS: J3.3; also elsewhere on the board
AIR_MAIN: J3.2; also elsewhere on the board
AIR_REDUNDANT: J3.1; also elsewhere on the board
CAN+: J5.7; also elsewhere on the board
CAN-: J5.1; also elsewhere on the board
DASH_TS_ON: J5.2; also elsewhere on the board
EBS_RESET _BUTTON: J5.3; also elsewhere on the board
GND: J2.3, J5.6; also elsewhere on the board
LINE: J1.3; also elsewhere on the board
NRST: J2.5; also elsewhere on the board
SAFETY_IN: J1.2; also elsewhere on the board
SAFETY_OUT: J1.4; also elsewhere on the board
SWDCLK: J2.2; also elsewhere on the board
SWDIO: J2.4; also elsewhere on the board
TS_ON_EXTERNAL: J5.8; also elsewhere on the board
VALVE_1_COIL_I: J4.1; also elsewhere on the board
VALVE_1_COIL_II: J4.3; also elsewhere on the board
VALVE_2_COIL_I: J4.2; also elsewhere on the board
VALVE_2_COIL_II: J4.4; also elsewhere on the board

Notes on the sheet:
10pin version not in stock ;/
HARWIN J-TEK
Connectors are divided intentionaly- Clue is to speed up inspection process where scrutineer will be unplugging different things and checking functional safety of the system
M80-5L11242MC
(AFTER RES 2)
M80-5L10442MC
so they are divided to sections to speed it up

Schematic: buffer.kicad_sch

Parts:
C34: 5.6n; C_0603_1608Metric_Pad1.08x0.95mm_HandSolder
C37: 100nF; C_0603_1608Metric
R38: 3.3k 1%; R_0603_1608Metric_Pad0.98x0.95mm_HandSolder
R39: 6.8k 1%; R_0603_1608Metric_Pad0.98x0.95mm_HandSolder
R40: 1k; R_0603_1608Metric_Pad0.98x0.95mm_HandSolder
U8: type="X" model="TSX7191" lib=""; SOT-23-5_HandSoldering

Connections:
+5V: C37.1, U8.4 (V+); also elsewhere on the board
/Air pressure sensor control/MAIN: R40.2; also elsewhere on the board
AIR_MAIN: R38.1; also elsewhere on the board
GND: C34.2, C37.2, R39.2, U8.5 (V-); also elsewhere on the board
unnamed: C34.1, R38.2, R39.1, U8.1 (+)
unnamed: R40.1, U8.2 (-), U8.3

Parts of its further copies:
C35, C36: 5.6n; C_0603_1608Metric_Pad1.08x0.95mm_HandSolder
C38, C39: 100nF; C_0603_1608Metric
R41, R44: 3.3k 1%; R_0603_1608Metric_Pad0.98x0.95mm_HandSolder
R42, R45: 6.8k 1%; R_0603_1608Metric_Pad0.98x0.95mm_HandSolder
R43, R46: 1k; R_0603_1608Metric_Pad0.98x0.95mm_HandSolder

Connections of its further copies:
+5V: C38.1, C39.1; also elsewhere on the board
/Air pressure sensor control/EBS: R43.2; also elsewhere on the board
/Air pressure sensor control/REDUNDANT: R46.2; also elsewhere on the board
AIR_EBS: R41.1; also elsewhere on the board
AIR_REDUNDANT: R44.1; also elsewhere on the board
GND: C35.2, C36.2, C38.2, C39.2, R42.2, R45.2; also elsewhere on the board
unnamed 53: C35.1, R41.2, R42.1; also elsewhere on the board
unnamed 54: C36.1, R44.2, R45.1; also elsewhere on the board
unnamed 78: R43.1; also elsewhere on the board
unnamed 79: R46.1; also elsewhere on the board

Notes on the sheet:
1k(sens out z)
PSE output impedance= 1kOhm

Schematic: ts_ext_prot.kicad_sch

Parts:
C29: 10nF; C_0603_1608Metric_Pad1.08x0.95mm_HandSolder
D13: BZX38450-C3V3-QX; D_SOD-323_HandSoldering
R28: 22k; R_0603_1608Metric_Pad0.98x0.95mm_HandSolder
R29: 3k; R_0603_1608Metric_Pad0.98x0.95mm_HandSolder

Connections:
/EBS Logic/TS_ON_EXT: C29.1, D13.1 (K), R28.2, R29.1; also elsewhere on the board
GND: C29.2, D13.2 (A), R29.2; also elsewhere on the board
TS_ON_EXTERNAL: R28.1; also elsewhere on the board

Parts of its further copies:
C30, C31: 10nF; C_0603_1608Metric_Pad1.08x0.95mm_HandSolder
D14, D15: BZX38450-C3V3-QX; D_SOD-323_HandSoldering
R30, R32: 22k; R_0603_1608Metric_Pad0.98x0.95mm_HandSolder
R31, R33: 3k; R_0603_1608Metric_Pad0.98x0.95mm_HandSolder

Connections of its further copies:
/EBS Logic/SAFETY_RESET_BUT: C31.1, D15.1 (K), R32.2, R33.1; also elsewhere on the board
/EBS Logic/TS_ON_COCKPIT: C30.1, D14.1 (K), R30.2, R31.1; also elsewhere on the board
DASH_TS_ON: R30.1; also elsewhere on the board
EBS_RESET _BUTTON: R32.1; also elsewhere on the board
GND: C30.2, C31.2, D14.2 (A), D15.2 (A), R31.2, R33.2; also elsewhere on the board

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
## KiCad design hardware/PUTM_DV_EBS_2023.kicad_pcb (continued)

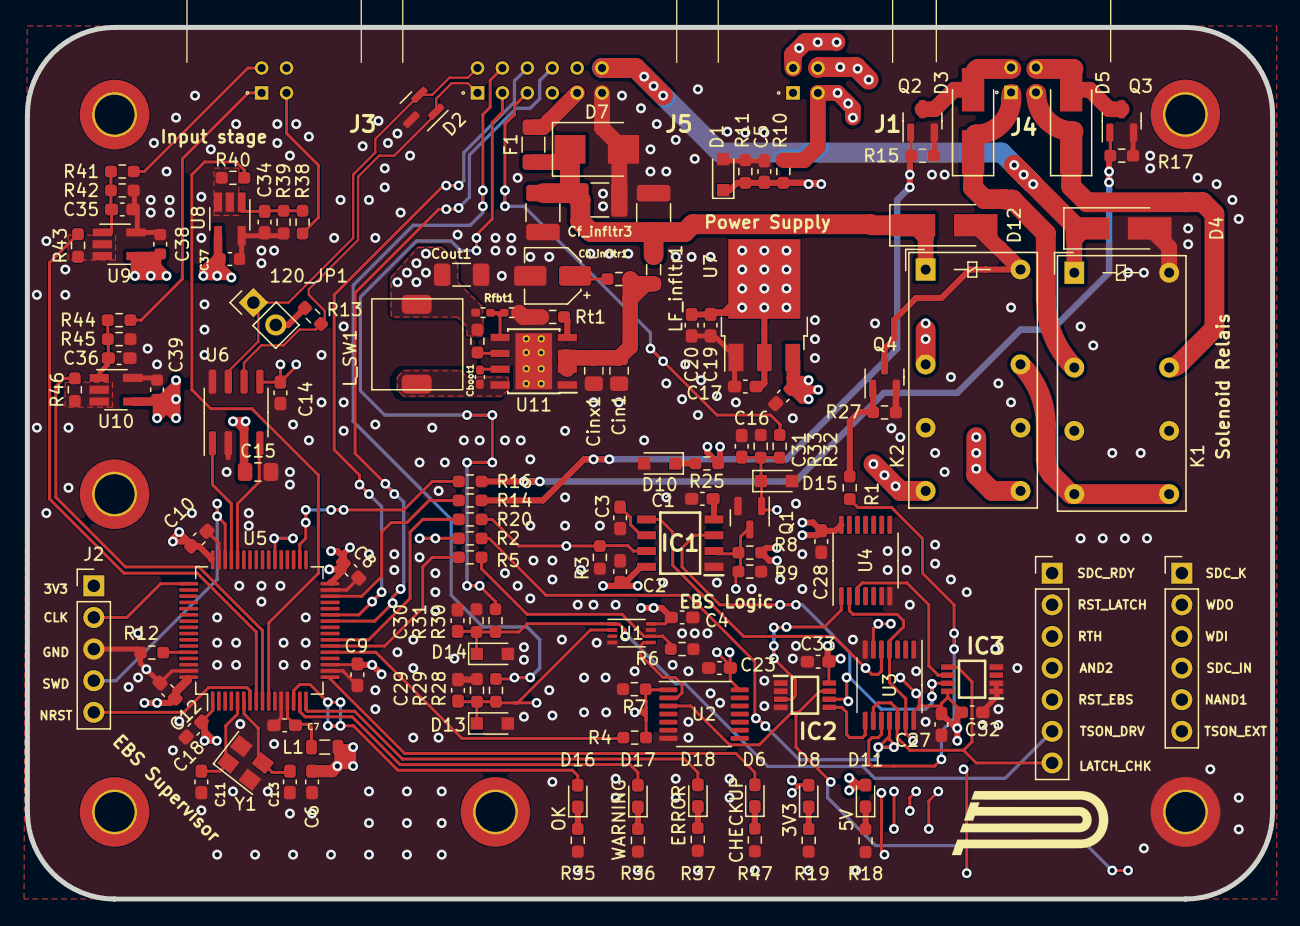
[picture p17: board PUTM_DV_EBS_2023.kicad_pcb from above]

Board: 4 copper layers, 100.0 x 70.0 mm, 145 parts (0 on the bottom side), 92 nets.

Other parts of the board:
H1, H2, H3, H4, H5, H6: MountingHole_3.2mm_M3_DIN965_Pad_TopBottom
PUTM_LOGO: LOGO; PUTM_LOGO_15mm
TP1: PinHeader_1x07_P2.54mm_Vertical
TP2: PinHeader_1x06_P2.54mm_Vertical
U9, U10: TSX7191; SOT-23-5_HandSoldering

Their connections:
+5V: U9.4 (V+), U10.4 (V+); also elsewhere on the board
/EBS Logic/AS COMMANDS OK: TP2.5; also elsewhere on the board
/EBS Logic/AS_CLOSE_SDC: TP2.1; also elsewhere on the board
/EBS Logic/RESET BUTTON LATCH: TP1.2; also elsewhere on the board
/EBS Logic/SAFETY_IN: TP2.4; also elsewhere on the board
/EBS Logic/SAFETY_LATCH_CHK: TP1.7; also elsewhere on the board
/EBS Logic/SAFETY_RESET_BUT: TP1.5; also elsewhere on the board
/EBS Logic/SDC READY: TP1.1; also elsewhere on the board
/EBS Logic/TS_ON_COCKPIT: TP1.6; also elsewhere on the board
/EBS Logic/TS_ON_EXT: TP2.6; also elsewhere on the board
/EBS Logic/WATCHDOG: TP2.3; also elsewhere on the board
/EBS Logic/WD + SAFETY OK: TP1.4; also elsewhere on the board
GND: H5.1, U9.5 (V-), U10.5 (V-); also elsewhere on the board
unnamed 53: U9.1 (+); also elsewhere on the board
unnamed 54: U10.1 (+); also elsewhere on the board
unnamed 65: TP1.3; also elsewhere on the board
unnamed 66: TP2.2; also elsewhere on the board
unnamed 78: U9.2 (-), U9.3; also elsewhere on the board
unnamed 79: U10.2 (-), U10.3; also elsewhere on the board

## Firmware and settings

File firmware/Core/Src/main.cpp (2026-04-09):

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
/* Includes
 * ------------------------------------------------------------------*/
#include "main.h"
#include "adc.h"
#include "can.h"
#include "dma.h"
#include "gpio.h"
#include "tim.h"

/* Private includes
 * ----------------------------------------------------------*/
/* USER CODE BEGIN Includes */
#include "PUTM_CAN_M.h"
#include "PUTM_EV_CAN_LIBRARY/include/can_driver.hpp"
#include "gpioElements.hpp"
#include "timer.hpp"

#include "math.h"
/* USER CODE END Includes */

/* Private typedef
 * -----------------------------------------------------------*/
/* Private define
 * ------------------------------------------------------------*/
/* USER CODE BEGIN PD */
#define USE_TEST 1

#define USE_TEST_POINTS 1

/* USER CODE END PD */

/* Private macro
 * -------------------------------------------------------------*/
/* USER CODE BEGIN PM */
enum Ebs_state {
  EBS_INITIAL_CHECKUP,
  EBS_CONTINOUS_MONITORING,
  EBS_STOP_MONITORING,
};

namespace config {
constexpr float brake_lower_bound = 6.5f;
constexpr float brake_upper_bound = 8.f;
constexpr float brake_press_deviation = 0.01f;
constexpr float can_brake_offset = -0.01f;
constexpr float press_tf_coef = 1.f;
constexpr float can_brake_lower_bound = 1.f;
constexpr float can_engaged_brakes_upper_bound = 90.f;
constexpr float can_engaged_brakes_lower_bound = 60.f;

constexpr uint32_t sdc_settle_timeout = 100;
constexpr uint32_t valve_settle_delay = 200;
constexpr uint32_t valve_settle_timeout = 200;

constexpr uint16_t can_timeout = 100;

constexpr uint32_t adc_count = 3;
}; // namespace config

struct Brake_data_can {
  uint16_t front;
  uint16_t rear;
  bool status;
} volatile brake_data_can;

struct Air_pressure_data_dma {
  uint16_t ebs;
  uint16_t redundant;
  uint16_t main;
} volatile air_pressure_data_dma;

struct TransferFcn {
  float a;
  float b;
  float solve(float x) { return a * x + b; }
};

class Brakes_data {
private:
  // driver_input.break_pressure* returns in kP and we use Bars, so times 0.01
  float convert_raw_data(uint16_t raw_data) {
    return static_cast<float>(raw_data) * 0.01f + config::can_brake_offset;
  }

public:
  float front;
  float rear;

  void update(volatile Brake_data_can &brake_data) {
    this->front = convert_raw_data(brake_data.front);
    this->rear = convert_raw_data(brake_data.rear);
  }

  bool check_buildup(float air_ebs) {
    if (this->front < config::press_tf_coef * air_ebs)
      return true;
    if (this->rear < config::press_tf_coef * air_ebs)
      return true;
    return false;
  }

  bool check_holdup_front(float air_ebs) {
    if (this->front > config::press_tf_coef * air_ebs &&
        this->rear < config::can_brake_lower_bound)
      return false;
    else
      return true;
  }

  bool check_holdup_rear(float air_ebs) {
    if (this->rear > config::press_tf_coef * air_ebs &&
        this->front < config::can_brake_lower_bound)
      return false;
    else
      return true;
  }

  bool check_engaged() {
    if (this->front > config::can_engaged_brakes_lower_bound &&
        this->front<config::can_engaged_brakes_upper_bound &&this->rear>
            config::can_engaged_brakes_lower_bound &&
        this->rear < config::can_engaged_brakes_upper_bound)
      return false;
    else
      return true;
  }
};

class Air_pressure_data {
private:
  // Transfer Function for Air pressure ADC readings:
  TransferFcn air_transferFcn = {3.227f, 620.0f};

public:
  float ebs;
  float redundant;
  float main;

  void update(volatile uint16_t air_pressure_data[config::adc_count]) {
    this->ebs = air_transferFcn.solve(static_cast<float>(air_pressure_data[0]));
    this->redundant =
        air_transferFcn.solve(static_cast<float>(air_pressure_data[1]));
    this->main =
        air_transferFcn.solve(static_cast<float>(air_pressure_data[2]));
  }

  bool check() {
    if (std::abs(this->ebs - this->redundant) > config::brake_press_deviation)
      return true;
    if (config::brake_lower_bound >= this->ebs ||
        this->ebs >= config::brake_upper_bound)
      return true;
    if (config::brake_lower_bound >= this->redundant ||
        this->redundant >= config::brake_upper_bound)
      return true;
    return false;
  }
};

/* USER CODE END PM */

/* Private variables
 * ---------------------------------------------------------*/

/* USER CODE BEGIN PV */

volatile uint16_t adc_dma_buffer[3];

/* GPIO Section */
GpioOutElement led_ok(LD_OK_GPIO_Port, LD_OK_Pin);
GpioOutElement led_warn(LD_WARN_GPIO_Port, LD_WARN_Pin);
GpioOutElement led_err(LD_ERR_GPIO_Port, LD_ERR_Pin);
GpioOutElement led_chk(LD_CHK_GPIO_Port, LD_CHK_Pin);

GpioOutElement as_close_sdc(AS_CLOSE_SDC_GPIO_Port, AS_CLOSE_SDC_Pin);
GpioOutElement as_mode(AS_MODE_GPIO_Port, AS_MODE_Pin);

GpioOutElement valve1(VALVE1_GPIO_Port, VALVE1_Pin);
GpioOutElement valve2(VALVE2_GPIO_Port, VALVE2_Pin);

GpioInElement sdc_ready(SDC_RDY_GPIO_Port, SDC_RDY_Pin);

/* Tests */
/* USER CODE END PV */

/* Private function prototypes
 * -----------------------------------------------*/
void SystemClock_Config(void);

/* USER CODE BEGIN PFP */
void startTogglingWatchdog();
void stopTogglingWatchdog();
void can_filter_config(CAN_HandleTypeDef *hcan);
void can_driver_input_cb(const PUTM_CAN_M_driver_input_t &driver_input);
void ebs_error();

/* USER CODE END PFP */

/* Private user code
 * ---------------------------------------------------------*/
/**
 * @brief  The application entry point.
 * @retval int
 */
int main(void) {
  /* MCU
   * Configuration--------------------------------------------------------*/

  /* Reset of all peripherals, Initializes the Flash interface and the
   * Systick.
   */
  HAL_Init();

  /* Configure the system clock */
  SystemClock_Config();

  /* Initialize all configured peripherals */
  MX_GPIO_Init();
  MX_DMA_Init();
  MX_TIM3_Init();
  MX_CAN1_Init();
  MX_ADC1_Init();
  /* USER CODE BEGIN 2 */
  Ebs_state ebs_state = EBS_INITIAL_CHECKUP;
  bool ebs_break = false;

  Brakes_data brakes;
  Air_pressure_data air_pressure;

  // Initialize CAN
  putm_ev_can::CanDriver can_m;
  can_filter_config(&hcan1);
  if (!can_m.Init(&hcan1)) {
    ebs_state = EBS_STOP_MONITORING;
  } else {
    can_m.RegisterCallback<PUTM_CAN_M_driver_input_t>(
        PUTM_CAN_M_DRIVER_INPUT_FRAME_ID, can_driver_input_cb);
  }

  HAL_ADCEx_Calibration_Start(&hadc1, ADC_SINGLE_ENDED);
  HAL_ADC_Start_DMA(&hadc1, (uint32_t *)adc_dma_buffer, config::adc_count);

  Timer sdc_timeout_timer(config::sdc_settle_timeout);
  Timer valve_timeout_timer(config::valve_settle_timeout);
  Timer can_timeout_timer(config::can_timeout);

  /* USER CODE END 2 */

  /* Infinite loop */
  /* USER CODE BEGIN WHILE */

  while (true) {
    switch (ebs_state) {

    case (EBS_INITIAL_CHECKUP): {
      // Turn on checkup led
      led_warn.activate();

      // Check if SDC is working
      startTogglingWatchdog();
      sdc_timeout_timer.restart();
      while (!sdc_ready.isActive()) {
        if (ebs_break = sdc_timeout_timer.checkIfTimedOutThenReset()) {
          ebs_error();
          break;
        }
      }
      if (ebs_break) {
        ebs_state = EBS_STOP_MONITORING;
        break;
      }
      stopTogglingWatchdog();
      sdc_timeout_timer.restart();
      while (sdc_ready.isActive()) {
        if (ebs_break = sdc_timeout_timer.checkIfTimedOutThenReset()) {
          ebs_error();
          break;
        }
      }
      if (ebs_break) {
        ebs_state = EBS_STOP_MONITORING;
        break;
      }
      startTogglingWatchdog();

      // Check that the EBS energy storage is filled
      air_pressure.update(adc_dma_buffer);
      if (air_pressure.check()) {
        ebs_error();
        ebs_state = EBS_STOP_MONITORING;
        break;
      }

      // Check CAN
      can_timeout_timer.restart();
      while (!brake_data_can.status) {
        if (ebs_break = can_timeout_timer.checkIfTimedOutThenReset()) {
          ebs_error();
          break;
        }
      }
      if (ebs_break) {
        ebs_state = EBS_STOP_MONITORING;
        break;
      }
      brakes.update(brake_data_can);
      brake_data_can.status = false;

      // Check that the brake pressure is built up correctly
      air_pressure.update(adc_dma_buffer);
      if (brakes.check_buildup(air_pressure.ebs)) {
        ebs_error();
        ebs_state = EBS_STOP_MONITORING;
        break;
      }

      // // Enable TS
      as_close_sdc.activate();

      // Wait for TS
      // Add checking TS from external signal/CAN

      // Check that the brake pressure is still built
      // up correctly #1
      valve1.activate();
      valve2.deactivate();
      HAL_Delay(config::valve_settle_delay);
      valve_timeout_timer.restart();
      while (brakes.check_holdup_front(air_pressure.ebs)) {
        if (ebs_break = valve_timeout_timer.checkIfTimedOutThenReset()) {
          ebs_error();
          break;
        }

        can_timeout_timer.restart();
        while (!brake_data_can.status) {
          if (ebs_break = can_timeout_timer.checkIfTimedOutThenReset()) {
            ebs_error();
            break;
          }
        }
        if (ebs_break) {
          break;
        }
        brakes.update(brake_data_can);
        brake_data_can.status = false;
      }
      if (ebs_break) {
        ebs_state = EBS_STOP_MONITORING;
        break;
      }

      // Check that the brake pressure is still built
      // up correctly #2
      valve1.deactivate();
      valve2.activate();
      HAL_Delay(config::valve_settle_delay);
      valve_timeout_timer.restart();
      while (brakes.check_holdup_rear(air_pressure.ebs)) {
        if (ebs_break = valve_timeout_timer.checkIfTimedOutThenReset()) {
          ebs_error();
          break;
        }

        can_timeout_timer.restart();
        while (!brake_data_can.status) {
          if (ebs_break = can_timeout_timer.checkIfTimedOutThenReset()) {
            ebs_error();
            break;
          }
        }
        if (ebs_break) {
          break;
        }
        brakes.update(brake_data_can);
        brake_data_can.status = false;
      }
      if (ebs_break) {
        ebs_state = EBS_STOP_MONITORING;
        break;
      }
      valve1.activate();
      valve2.activate();

      // Start continous monitoring
      led_warn.deactivate();
      led_ok.activate();
      ebs_state = EBS_CONTINOUS_MONITORING;
      break;
    }

    case EBS_CONTINOUS_MONITORING: {

      // Monitor the storage of brake energy (air pressure)
      air_pressure.update(adc_dma_buffer);
      if (air_pressure.check()) {
        ebs_error();
        ebs_state = EBS_STOP_MONITORING;
        break;
      }
      // // Convert brake pressure data from if received from CAN
      // if (brake_data_can.status == true) {
      //   brakes.update(brake_data_can);
      //   brake_data_can.status = false;
      // }

      // Check RES state CAN OK?
      // AS OK?

      // // Check SDC
      // if (!sdc_ready.isActive()) {
      //   HAL_Delay(config::valve_settle_delay);
      //   valve_timeout_timer.restart();
      //   while (brakes.check_engaged()) {
      //     if (ebs_break = valve_timeout_timer.checkIfTimedOutThenReset()) {
      //       ebs_error();
      //       break;
      //     }

      //     can_timeout_timer.restart();
      //     while (!brake_data_can.status) {
      //       if (ebs_break = can_timeout_timer.checkIfTimedOutThenReset()) {
      //         ebs_error();
      //         break;
      //       }
      //     }
      //     if (ebs_break)
      //       break;

      //     brakes.update(brake_data_can);
      //     brake_data_can.status = false;
      //   }
      //   if (ebs_break) {
      //     ebs_state = EBS_STOP_MONITORING;
      //     break;
      //   }
      // }

      break;
    }
    case EBS_STOP_MONITORING: {
      if (sdc_ready.isActive()) {
        led_err.deactivate();
        ebs_break = false;
        ebs_state = EBS_INITIAL_CHECKUP;
        // Add proper ASB reset
      }
      break;
    }
    }
    /* USER CODE END WHILE */

  }
}
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
/* USER CODE BEGIN 4 */

void can_driver_input_cb(const PUTM_CAN_M_driver_input_t &driver_input) {
  brake_data_can.front = driver_input.brake_pressure_front;
  brake_data_can.rear = driver_input.brake_pressure_rear;
  brake_data_can.status = true;
}

void can_filter_config(CAN_HandleTypeDef *hcan) {
  constexpr static CAN_FilterTypeDef sFilterConfig{
      .FilterIdHigh = 0x0000,
      .FilterIdLow = 0x0000,
      .FilterMaskIdHigh = 0x0000,
      .FilterMaskIdLow = 0x0000,
      .FilterFIFOAssignment = CAN_RX_FIFO0,
      .FilterBank = 0,
      .FilterMode = CAN_FILTERMODE_IDMASK,
      .FilterScale = CAN_FILTERSCALE_32BIT,
      .FilterActivation = ENABLE,
      .SlaveStartFilterBank = 14};

  if (HAL_CAN_ConfigFilter(hcan, &sFilterConfig) != HAL_OK) {
    Error_Handler();
  }
}

void ebs_error() {
  led_ok.deactivate();
  led_warn.deactivate();
  led_err.activate();
  valve1.deactivate();
  valve2.deactivate();
  as_close_sdc.deactivate();
  return;
}

void startTogglingWatchdog() { HAL_TIM_PWM_Start(&htim3, TIM_CHANNEL_2); }

void stopTogglingWatchdog() { HAL_TIM_PWM_Stop(&htim3, TIM_CHANNEL_2); }

/* USER CODE END 4 */
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


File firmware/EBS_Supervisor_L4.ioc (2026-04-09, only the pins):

Mcu.UserName=STM32L4P5RETx
PA0.GPIO_Label=LD_OK
PA0.Signal=GPIO_Output
PA1.GPIO_Label=LD_WARN
PA1.Signal=GPIO_Output
PA11.Signal=CAN1_RX
PA12.Signal=CAN1_TX
PA2.GPIO_Label=LD_ERR
PA2.Signal=GPIO_Output
PA3.GPIO_Label=LD_CHK
PA3.Signal=GPIO_Output
PA5.GPIO_Label=AS_CLOSE_SDC
PA5.Signal=GPIO_Output
PA6.GPIO_Label=AS_MODE
PA6.Signal=GPIO_Output
PA7.Signal=S_TIM3_CH2
PB11.GPIO_Label=VALVE1
PB11.Signal=GPIO_Output
PB13.GPIO_Label=VALVE2
PB13.Signal=GPIO_Output
PC0.GPIO_Label=AIR_EBS
PC0.Signal=ADCx_IN1
PC1.GPIO_Label=AIR_RDNT
PC1.Signal=ADCx_IN2
PC2.GPIO_Label=AIR_MAIN
PC2.Signal=ADCx_IN3
PC7.GPIO_Label=SDC_RDY
PC7.Signal=GPIO_Input

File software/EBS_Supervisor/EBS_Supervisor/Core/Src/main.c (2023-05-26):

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
/* Includes ------------------------------------------------------------------*/
#include "main.h"

/* USER CODE BEGIN Includes */

#include <functional>
#include <math.h>

#include "timer.hpp"
#include "gpioElements.hpp"
#include "PUTM_EV_CAN_LIBRARY/lib/can_interface.hpp"

/* USER CODE END Includes */

/* USER CODE BEGIN PD */

#define USE_TEST 1

#define USE_TEST_POINTS 1

/* USER CODE END PD */

/* USER CODE BEGIN PM */
struct Fun
{
	float a;
	float b;
	float solve(float x) { return a * x + b; }
};

/* USER CODE END PM */

ADC_HandleTypeDef hadc1;
DMA_HandleTypeDef hdma_adc1;

CAN_HandleTypeDef hcan;

TIM_HandleTypeDef htim3;

/* USER CODE BEGIN PV */

const int adc_count = 3;

volatile uint16_t adc_dma_buffer[3];

uint16_t can_timeout_counter;

Fun air_fun = { 0.0026308866087872f, -2.00210470928703f };

volatile float air_ebs;
volatile float air_redundant;
volatile float air_main;

/* GPIO Section */
GpioOutElement led_ok(LD_OK_GPIO_Port, LD_OK_Pin);
GpioOutElement led_warn(LD_WARN_GPIO_Port, LD_WARN_Pin);
GpioOutElement led_err(LD_ERR_GPIO_Port, LD_ERR_Pin);
GpioOutElement led_chk(LD_CHK_GPIO_Port, LD_CHK_Pin);

GpioOutElement as_close_sdc(AS_CLOSE_SDC_GPIO_Port, AS_CLOSE_SDC_Pin);
GpioOutElement as_mode(AS_MODE_GPIO_Port, AS_MODE_Pin);

GpioOutElement spare1(spare1_GPIO_Port, spare1_Pin);
GpioOutElement spare2(spare2_GPIO_Port, spare2_Pin);

GpioOutElement valve1(VALVE1_GPIO_Port, VALVE1_Pin);
GpioOutElement valve2(VALVE2_GPIO_Port, VALVE2_Pin);

GpioInElement sdc_ready(SDC_RDY_GPIO_Port, SDC_RDY_Pin);

static struct Config
{
	constexpr static float brake_lower_bound = 6.5f;
	constexpr static float brake_upper_bound = 8.f;
	constexpr static float brake_press_deviation = 0.01f;
	constexpr static float can_brake_offset = -0.01f;
	constexpr static float press_tf_coef = 1.f;
	constexpr static float can_brake_lower_bound = 1.f;
	constexpr static float can_engaged_brakes_upper_bound = 90.f;
	constexpr static float can_engaged_brakes_lower_bound = 60.f;

	constexpr static uint32_t sdc_settle_timeout = 100;
	constexpr static uint32_t valve_settle_delay = 200;
	constexpr static uint32_t valve_settle_timeout = 200;

	constexpr static uint16_t can_timeout = 100;
} volatile config;

/* Tests */
#if USE_TEST_POINTS
struct TestPoints
{
	volatile const uint16_t &air_ebs_adc = adc_dma_buffer[0];
	volatile const uint16_t &air_redundant_adc = adc_dma_buffer[1];
	volatile const uint16_t &air_main_adc = adc_dma_buffer[2];
	volatile float &air_ebs_ = air_ebs;
	volatile float &air_redundant_adc_ = air_redundant;
	volatile float &air_main_adc_ = air_main;

	volatile bool sdc_ready = false;
} volatile test_points;
#endif

/* USER CODE END PV */

void SystemClock_Config(void);
static void MX_GPIO_Init(void);
static void MX_DMA_Init(void);
static void MX_ADC1_Init(void);
static void MX_CAN_Init(void);
static void MX_TIM3_Init(void);
/* USER CODE BEGIN PFP */

void starTogglingWatchdog();
void stopTogglingWatchdog();

/* USER CODE END PFP */

/**
  * @brief  The application entry point.
  * @retval int
  */
int main(void)
{
  /* MCU Configuration--------------------------------------------------------*/

  /* Reset of all peripherals, Initializes the Flash interface and the Systick. */
  HAL_Init();

  /* Configure the system clock */
  SystemClock_Config();

  /* Initialize all configured peripherals */
  MX_GPIO_Init();
  MX_DMA_Init();
  MX_ADC1_Init();
  MX_CAN_Init();
  MX_TIM3_Init();
  /* USER CODE BEGIN 2 */
	HAL_ADCEx_Calibration_Start(&hadc1);
	HAL_ADC_Start_DMA(&hadc1, (uint32_t*)adc_dma_buffer, adc_count);
//
//	//--------------------------------------------------------------------------------------------------------------------
//	//Initial checkup
//
//	//check if sdc is working
//	Timer sdc_timeout_timer(config.sdc_settle_timeout);
//	starTogglingWatchdog();
//	while(true)
//	{
//		if(sdc_timeout_timer.checkIfTimedOutThenReset()) Error_Handler();
//		if(sdc_ready.isActive()) break;
//	}
//
//	sdc_timeout_timer.restart();
//	stopTogglingWatchdog();
//	while(true)
//	{
//		if(sdc_timeout_timer.checkIfTimedOutThenReset()) Error_Handler();
//		if(!sdc_ready.isActive()) break;
//	}
//
//	starTogglingWatchdog();
//
//	//check pressure
//	if(std::abs(air_ebs - air_redundant) > config.brake_press_deviation) Error_Handler();
//	if(config.brake_lower_bound >= air_ebs || air_ebs >= config.brake_upper_bound) Error_Handler();
//	if(config.brake_lower_bound >= air_redundant || air_redundant >= config.brake_upper_bound) Error_Handler();
//
//	auto aq_main = PUTM_CAN::can.get_aq_main();
//
//	//aq_main.break_press returns in kP and we use Bars, so times 0.01
//	float brake_press_front = aq_main.brake_pressure_front * 0.01f + config.can_brake_offset;
//	float brake_press_rear = aq_main.brake_pressure_back * 0.01f + config.can_brake_offset;
//
//	if(brake_press_front < config.press_tf_coef * air_ebs) Error_Handler();
//	if(brake_press_rear < config.press_tf_coef * air_ebs) Error_Handler();
//
//	//wait for tc enabled
//	bool tc_activated = false;
//	do
//	{
//		HAL_Delay(100);
//		auto tc_main = PUTM_CAN::can.get_tc_main();
//		tc_activated = tc_main.traction_control_enable;
//	} while(!tc_activated);
//
//	//check valves
//	valve1.activate();
//	valve2.deactivate();
//	HAL_Delay(config.valve_settle_delay);
//	Timer valve_timeout_timer(config.valve_settle_timeout);
//	while(true)
//	{
//		if(valve_timeout_timer.checkIfTimedOutThenReset()) Error_Handler();
//		if(PUTM_CAN::can.get_aq_main_new_data())
//		{
//			aq_main = PUTM_CAN::can.get_aq_main();
//
//			brake_press_front = aq_main.brake_pressure_front * 0.01f + config.can_brake_offset;
//			brake_press_rear = aq_main.brake_pressure_back * 0.01f + config.can_brake_offset;
//		}
//		if(brake_press_front > config.press_tf_coef * air_ebs && brake_press_rear < config.can_brake_lower_bound) break;
//	}
//	valve1.activate();
//	valve2.deactivate();
//	HAL_Delay(config.valve_settle_delay);
//	valve_timeout_timer.restart();
//	while(true)
//	{
//		if(valve_timeout_timer.checkIfTimedOutThenReset()) Error_Handler();
//		if(PUTM_CAN::can.get_aq_main_new_data())
//		{
//			aq_main = PUTM_CAN::can.get_aq_main();
//
//			brake_press_front = aq_main.brake_pressure_front * 0.01f + config.can_brake_offset;
//			brake_press_rear = aq_main.brake_pressure_back * 0.01f + config.can_brake_offset;
//		}
//		if(brake_press_rear > config.press_tf_coef * air_ebs && brake_press_front < config.can_brake_lower_bound) break;
//	}



  /* USER CODE END 2 */

  /* Infinite loop */
  /* USER CODE BEGIN WHILE */
	//--------------------------------------------------------------------------------------------------------------------
	//continuous monitoring
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

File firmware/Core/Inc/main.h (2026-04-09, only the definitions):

#define AIR_EBS_Pin GPIO_PIN_0
#define AIR_EBS_GPIO_Port GPIOC
#define AIR_RDNT_Pin GPIO_PIN_1
#define AIR_RDNT_GPIO_Port GPIOC
#define AIR_MAIN_Pin GPIO_PIN_2
#define AIR_MAIN_GPIO_Port GPIOC
#define LD_OK_Pin GPIO_PIN_0
#define LD_OK_GPIO_Port GPIOA
#define LD_WARN_Pin GPIO_PIN_1
#define LD_WARN_GPIO_Port GPIOA
#define LD_ERR_Pin GPIO_PIN_2
#define LD_ERR_GPIO_Port GPIOA
#define LD_CHK_Pin GPIO_PIN_3
#define LD_CHK_GPIO_Port GPIOA
#define AS_CLOSE_SDC_Pin GPIO_PIN_5
#define AS_CLOSE_SDC_GPIO_Port GPIOA
#define AS_MODE_Pin GPIO_PIN_6
#define AS_MODE_GPIO_Port GPIOA
#define VALVE1_Pin GPIO_PIN_11
#define VALVE1_GPIO_Port GPIOB
#define VALVE2_Pin GPIO_PIN_13
#define VALVE2_GPIO_Port GPIOB
#define SDC_RDY_Pin GPIO_PIN_7
#define SDC_RDY_GPIO_Port GPIOC

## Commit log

2022-10-15 Initial commit, schematic v1
    Just making a little cleanup on GitHub
    [PUTM_DV_EBS_2023.kicad_pcb, PUTM_DV_EBS_2023.kicad_sch, latch.kicad_sch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]
2022-10-18 Fixed Logic
    [PUTM_DV_EBS_2023.kicad_sch, logic.kicad_sch, output.kicad_sch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]
2022-10-18 Alpha 1.0.0 Schematic
    First Schematic Version for initial checkup
    [PUTM_DV_EBS_2023.kicad_sch, logic.kicad_sch, output.kicad_sch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]
2022-10-20 Minor changes on v1 schematic
    [PUTM_DV_EBS_2023.kicad_sch, latch.kicad_sch, logic.kicad_sch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]
2022-11-05 minor schematic cleanup
    Fixes before second review
    [PUTM_DV_EBS_2023.kicad_sch, connector.kicad_sch, latch.kicad_sch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]
2022-11-05 Schematic ready for second review
    Cleaned up, numerated, added footprints, JW notes considered
    [PUTM_DV_EBS_2023.kicad_sch, connector.kicad_sch, latch.kicad_sch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]
2022-11-15 0xERC State
    Schematic needs only simulation and veryfying component choice for now
    [2-1393779-0.stp, PUTM_DV_EBS_2023.kicad_pcb, PUTM_DV_EBS_2023.kicad_sch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]
2022-11-19 Last schematic todo changes, mother slander on PCB
    [PUTM_DV_EBS_2023.kicad_pcb, PUTM_DV_EBS_2023.kicad_sch, sensors.kicad_sch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]
2022-12-05 working simulations, assigned footprints
    "nightly" relase
    [PUTM_DV_EBS_2023.kicad_sch, buffer.kicad_sch, connector.kicad_sch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]
2022-12-06 minor changes
    pre spotkanie comiit ;DD
    [PUTM_DV_EBS_2023.kicad_pcb, PUTM_DV_EBS_2023.kicad_sch, buffer.kicad_sch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]
2022-12-06 kończymy balet na dziś
    [PUTM_DV_EBS_2023.kicad_pcb, PUTM_DV_EBS_2023.kicad_sch, buffer.kicad_sch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]
2022-12-08 begin of placement process, supply section done
    będą obłe ścieżki i chuj
    [PUTM_DV_EBS_2023.kicad_pcb]
2022-12-08 JLC fabrication adjustments, assigned nets
    sluchajcie historii typ jakis z ryjem do mnie na swiatlach AWF bo pozno ruszylem pozniej sie ustawilismy kolo siebie i go zjadlem na acceleration new beetlem bo ma 110 koni jebaniec pozdrawiam frajer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
    [PUTM_DV_EBS_2023.kicad_pcb]
2022-12-09 dobra ide spać
    [PUTM_DV_EBS_2023.kicad_pcb, connector.kicad_sch, logic.kicad_sch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]
2022-12-10 full 3d models, pre-routing, corrections
    kurwa bezpiecznik od wczoraj a fura dalej nie jeździ siedze u rakietowcow bo cieplo chlopaki co z wami
    [PUTM_DV_EBS_2023.kicad_pcb, PUTM_DV_EBS_2023.kicad_sch, connector.kicad_sch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]
2022-12-11 still working
    [PUTM_DV_EBS_2023.kicad_pcb, PUTM_DV_EBS_2023.kicad_sch, supervisor.kicad_sch]
2022-12-12 kurde no jeszcze nie skonczylem ale sune dalej
    [PUTM_DV_EBS_2023.kicad_pcb, PUTM_DV_EBS_2023.kicad_sch, buffer.kicad_sch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]
2022-12-14 fixed references addet tp;s mam pojutrze przejebany egzamin nara
    [PUTM_DV_EBS_2023.kicad_pcb, PUTM_DV_EBS_2023.kicad_sch, buffer.kicad_sch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]
2022-12-20 supply section redesign due to IC shortage
    [PUTM_DV_EBS_2023.kicad_pcb, PUTM_DV_EBS_2023.kicad_sch, supervisor.kicad_sch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]
2022-12-20 routing update, new supply section routed
    [PUTM_DV_EBS_2023.kicad_pcb, PUTM_DV_EBS_2023.kicad_sch, connector.kicad_sch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]
2022-12-21 PCB in review and DRC error delete state, please check it
    [PUTM_DV_EBS_2023.kicad_pcb, PUTM_DV_EBS_2023.kicad_sch, supervisor.kicad_sch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]
2022-12-22 DRC fixes part 1
    [PUTM_DV_EBS_2023.kicad_pcb, PUTM_DV_EBS_2023.kicad_sch, connector.kicad_sch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]
2022-12-23 Alpha 1.0 Hardware relase. 0xDRC state, improved aesthetics and signal integrity
    [PUTM_DV_EBS_2023.kicad_pcb, connector.kicad_sch, supply.kicad_sch]
2022-12-28 Last touches,PCB ready to order
    [PUTM_DV_EBS_2023.kicad_pcb, supply.kicad_sch]
2022-12-29 minor aestethics improvement
    [PUTM_DV_EBS_2023.kicad_pcb, PUTM_DV_EBS_2023.kicad_sch, connector.kicad_sch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]
2023-01-04 GND improvement after Review (taka masa ze sie wengoz zesra)
    [PUTM_DV_EBS_2023.kicad_pcb, PUTM_DV_EBS_2023.kicad_sch, connector.kicad_sch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]
2023-02-20 uga baga commmit hardware
    [supervisor.kicad_sch, supply.kicad_sch]
2023-02-21 Masz Piotruś
    [PUTM_DV_EBS_2023.kicad_pcb, PUTM_DV_EBS_2023.kicad_sch, supervisor.kicad_sch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]
2023-07-07 L4 port
    [PUTM_DV_EBS_2023.kicad_sch, buffer.kicad_sch, connector.kicad_sch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]
2023-07-13 first working state, valves forced activation
    [PUTM_DV_EBS_2023.kicad_pcb, PUTM_DV_EBS_2023.kicad_sch, logic.kicad_sch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]
2023-09-18 Schematic redesign for 23 rules, new pressure buffer, protection fix
    [PUTM_DV_EBS_2023.kicad_pcb, PUTM_DV_EBS_2023.kicad_sch, buffer.kicad_sch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]
2023-09-20 WIP revision 2 layout refinement
    [PUTM_DV_EBS_2023.kicad_pcb, buffer.kicad_sch, connector.kicad_sch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]
2023-09-29 2.0 layot wip, each sections placed
    [PUTM_DV_EBS_2023.kicad_pcb, connector.kicad_sch, logic.kicad_sch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]
2023-10-02 WIP 1.1 routing
    [PUTM_DV_EBS_2023.kicad_pcb, connector.kicad_sch, latch.kicad_sch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]
2023-10-02 2.0 layot wip , routing 2
    [PUTM_DV_EBS_2023.kicad_pcb, supply.kicad_sch]
2023-10-03 2.0 layot wip , routing 3
    [PUTM_DV_EBS_2023.kicad_pcb, PUTM_DV_EBS_2023.kicad_sch, connector.kicad_sch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]
2023-10-12 Dimensions compress, routing
    [PM08_Fanout.kicad_pcb, PM08_Fanout.kicad_sch, PUTM_DV_EBS_2023.kicad_pcb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]
2023-10-17 replace RES2 input to actuator relai
    [PUTM_DV_EBS_2023.kicad_pcb, PUTM_DV_EBS_2023.kicad_sch, connector.kicad_sch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]
2023-10-23 Adjust mounting holes to FBOX and BSPD
    [PUTM_DV_EBS_2023.kicad_pcb, connector.kicad_sch, supply.kicad_sch]
2023-10-30 0xDRC state 1.1 ready for review
    [PUTM_DV_EBS_2023.kicad_pcb]
2023-11-17 Main board 1.1 production files
    [PM08_Fanout.kicad_pcb, PUTM_DV_EBS_2023.kicad_pcb]
2023-11-18 Added PM08 connector board
    [PM08_Fanout.kicad_pcb, PM08_Fanout.kicad_sch]
2023-12-10 Succesful pressure value send over CAN, DMA fix
    [EBS_Supervisor_L4.ioc, main.cpp]
2026-03-17 Fixed cmake target_-lik_libraries problem
    [main.cpp]
2026-03-17 can init and brake pressure receive callback
2026-03-17 added can filter
2026-03-19 added methods for checking pressure
2026-03-22 fixed brake variable name
    [main.cpp]
2026-03-26 changed pcb version
    [PM08_Fanout.kicad_pcb, PM08_Fanout.kicad_sch, PUTM_DV_EBS_2023.kicad_pcb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]
2026-03-31 uploaded older pcb version
    [PUTM_DV_EBS_2023.kicad_sch, buffer.kicad_sch, connector.kicad_sch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]
2026-03-31 kicad 10 port
    [PUTM_DV_EBS_2023.kicad_pcb]
2026-04-06 fixed adc callback
2026-04-09 fixed adc reading

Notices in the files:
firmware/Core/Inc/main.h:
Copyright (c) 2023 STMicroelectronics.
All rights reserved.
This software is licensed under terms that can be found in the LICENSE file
